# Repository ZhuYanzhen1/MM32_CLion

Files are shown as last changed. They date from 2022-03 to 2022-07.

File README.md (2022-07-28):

# MM32_CLion

&nbsp;&nbsp;&nbsp;&nbsp;&nbsp;&nbsp;&nbsp;&nbsp;&nbsp;&nbsp;&nbsp;&nbsp;English / [中文](https://github.com/ZhuYanzhen1/MM32_CLion/blob/master/README_CN.md)

&nbsp;&nbsp;&nbsp;&nbsp;This project is a Windows CLion IDE file for the MM32F3277G9 chip and a circuit design for the main control board based on the MM32F3277G9 chip. The software code contains the link files required for GCC, CMake files, clang-format files, Doxygen configuration files, etc. to ensure that this package is ready to use when it arrives. The hardware mainly contains the schematic and PCB files, and the Gerber files will be released in the form of Releases.The adapted tuning tool is developed using Qt, and the repository contains the Qt source code files for the tool. Some Python scripting tools are also provided for easy development, such as scripts for calculating filter parameters.<br>
&nbsp;&nbsp;&nbsp;&nbsp;This project is developed around the 2022 National Student Intelligent Vehicle Competition. Complex algorithms such as LQR controller, multi-rate Kalman fusion, and advanced development tools such as unit testing and continuous integration are innovatively used in this project for development, which greatly improves the development efficiency and reduces the development cost.

***

### Develop Environment

+ Integrated Development Environment: CLion CL-221.5921.27
+ OS: Windows 10 Professional 21H2 x64 10.0.19044
+ Make tool: GNU Make 4.3 x86_64-w64-mingw32
+ Compiler tool chain: gcc-arm-none-eabi 10.3.1 20210824
+ Burning tool: OpenOCD 0.11.0+dev-00449-gb2ab2241f+ (2021-11-13-20:25)
+ Documentation tool: Doxygen GUI 1.9.4 (Qt version 5.15.2)
+ EDA tool: KiCAD 6.0.5 (VC++ 1929, 64bit)
+ Qt environment: Qt 5.14.2 (MSVC 2017, 32bit)
+ Python version: Python 3.10.5 [MSC v.1929 64 bit (AMD64)] on win32

***

### Directory Structure

+ .github: Configuration file for the continuous integration of Github Actions.
+ circuit: Schematics and PCB files related to the project.
  + bldc_driver: Schematic and PCB file of the brushless driver board.
  + control_board: Schematic and PCB file of the main control board.
  + geomagnetometer: Schematic and PCB file of geomagnetometer board.
  + power_board: Schematic and PCB file of the power supply board.
  + uart_tt_mcu: Schematic and PCB file of serial transmission module microcontroller side.
  + uart_tt_pc: Schematic and PCB file of the PC side of the serial port pass-through module.
  + wireless_debugger: Schematic and PCB file of the wireless debugger.
+ docs: html documents and related images and board interactive BOMs generated by Doxygen.
+ mechanical: 3D model files of non-standard mechanical parts.
  + battery_mount: 3D model file of the battery mount.
  + car_shell: 3D model file of the car shell.
  + control_board_mount: 3D model file of main control board and power board bracket.
  + magnometer_mount: 3D model file of geomagnetometer bracket.
+ program: Source file and configuration file of the main controller program.
  + ctrl_mcu: control MCU user layer code, main logic implementation.
  + debug: transmission layer code and CMBackTrace program file for implementing serial port tuning reference.
  + device: Device specific data link layer protocol to implement device level register read/write.
  + fatfs: code related to the FAT file system.
  + form: All form controls and form actions for the display.
  + freertos: code for the FreeRTOS real-time operating system.
  + gui: the relevant drawing functions and forms code implementation for the display.
  + hardware: initialization and read/write code related to MM32F3277G9P chip peripherals.
  + library: code for the HAL library of the MM32F3277G9P chip provided by MindMotion.
  + math: code and functions related to math calculation, such as checksum calculation, FFT, etc.
  + proc_mcu: Handling MCU user layer code, main logic implementation.
  + protocol: data link layer transmission protocol for [sdtp and mdtp](https://github.com/ZhuYanzhen1/CDTP).
  + system: initialization and operation code related to MM32F3277G9P system.
+ scripts: Python script files used to facilitate program testing and design.
+ testbench: CUnit library-based unit test code for testing functions.
+ tools: Qt tuning tool source code used for tuning parameters.

***

### License

**Affiliation：AcmeTech<br>
Author: Yanzhen Zhu, Guilin Zhao, Hanbing Lai<br>
Maintainer：Yanzhen Zhu, Guilin Zhao, 2208213223@qq.com, 1662568794@qq.com**

&nbsp;&nbsp;&nbsp;&nbsp;The source code is released under a [AGPL-3.0 License](https://github.com/ZhuYanzhen1/MM32_CLion/blob/master/LICENSE).The product has been tested under Windows 10 and Ubuntu 18.04 and 20.04. This is research code, expect that it changes often and any fitness for a particular purpose is disclaimed.

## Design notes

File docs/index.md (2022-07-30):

## Welcome to GitHub Pages / 欢迎来到GitHub Pages
&nbsp;&nbsp;&nbsp;&nbsp;This Github Pages page is used to deploy and display report files automatically generated or manually exported through Github Actions, interactive BOMs for boards, and description manuals for program code. This page is a guide page, and you can go to it by clicking the appropriate option.<br>
&nbsp;&nbsp;&nbsp;&nbsp;本Github Pages页面用于部署和展示通过Github Actions自动生成或手动导出的报告文件、电路板的交互式BOM以及程序代码的描述手册。本页面是引导页，你可以通过点击相应选项前往该页面。

***

### Program Manual / 程序手册
[Program Manual / 程序手册](https://zhuyanzhen1.github.io/MM32_CLion/doxygen/index.html)

***

### Unit Test / 单元测试
[Unit Test Results / 单元测试结果](https://zhuyanzhen1.github.io/MM32_CLion/unit_test/Report-Results.xml)<br>
[Unit Test List / 单元测试列表](https://zhuyanzhen1.github.io/MM32_CLion/unit_test/Report-Listing.xml)

***

### Interactive BOM / 交互式BOM
[Interactive BOM for ControlBoard / 主控板交互式BOM](https://zhuyanzhen1.github.io/MM32_CLion/circuit/control_board_ibom.html)<br>
[Interactive BOM for BLDC Driver / 无刷电机驱动板交互式BOM](https://zhuyanzhen1.github.io/MM32_CLion/circuit/bldc_driver_ibom.html)<br>
[Interactive BOM for Wireless Debugger / 无线调试器交互式BOM](https://zhuyanzhen1.github.io/MM32_CLion/circuit/wireless_debugger_ibom.html)<br>
[Interactive BOM for PC-side Wireless Serial / PC端串口透传交互式BOM](https://zhuyanzhen1.github.io/MM32_CLion/circuit/uart_tt_pc_ibom.html)<br>
[Interactive BOM for MCU-side Wireless Serial / MCU端串口透传交互式BOM](https://zhuyanzhen1.github.io/MM32_CLion/circuit/uart_tt_mcu_ibom.html)<br>
[Interactive BOM for Geomagnometer / 地磁计交互式BOM](https://zhuyanzhen1.github.io/MM32_CLion/circuit/geomagnetometer_ibom.html)

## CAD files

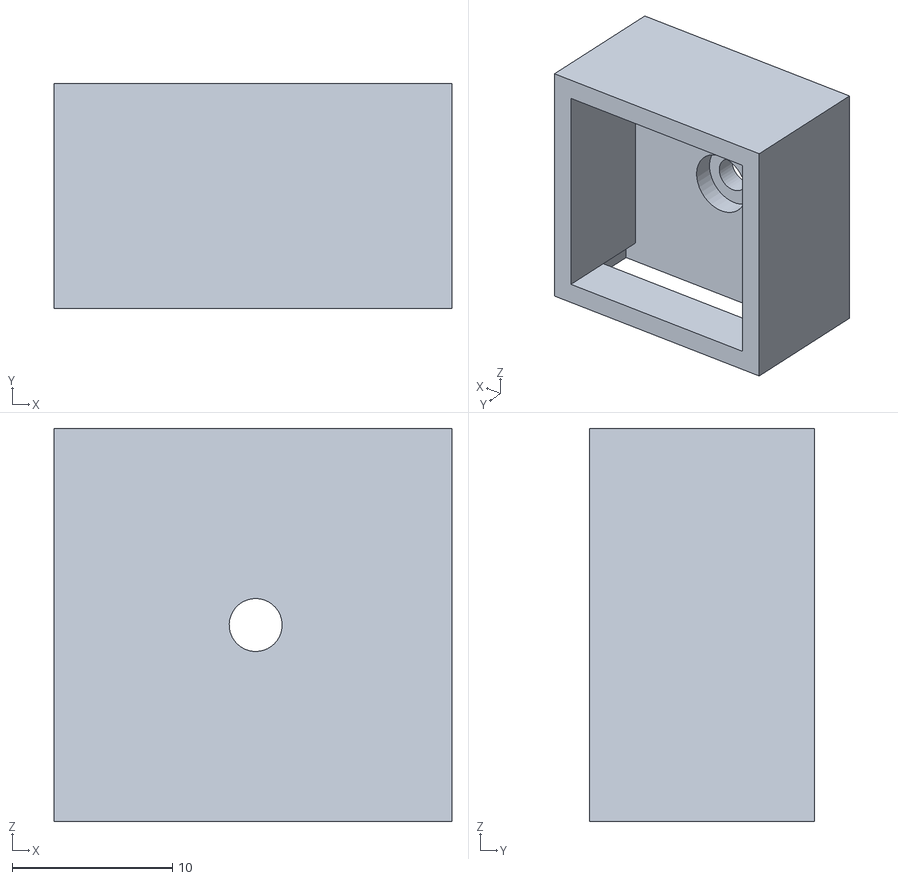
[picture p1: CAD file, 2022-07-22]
mechanical/magnometer_mount.STL
24.8 x 14.0 x 24.5

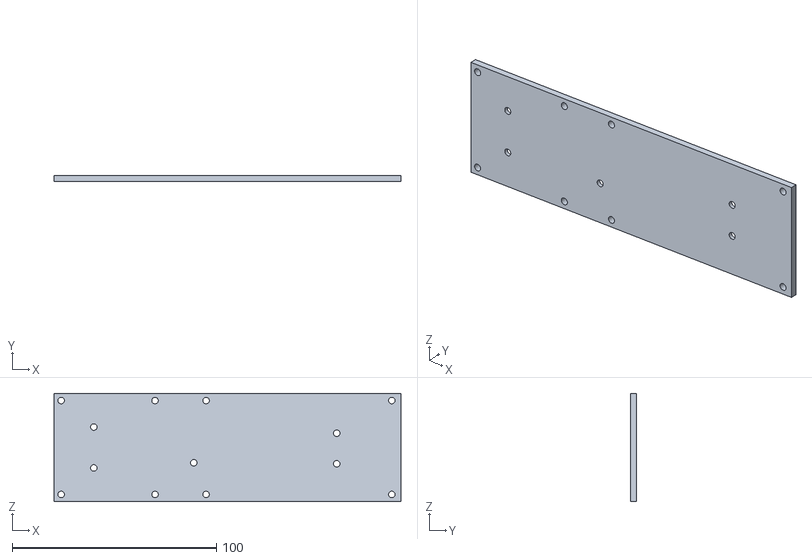
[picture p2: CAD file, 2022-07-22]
mechanical/controlboard_mount.STL
170.0 x 3.00 x 53.0

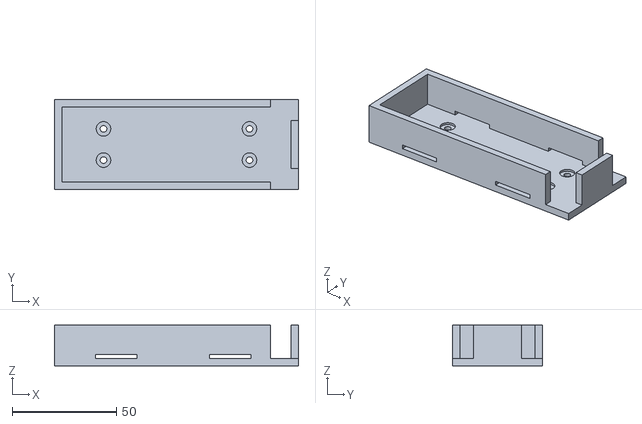
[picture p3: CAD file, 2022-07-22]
mechanical/baterry_mount.STL
117.0 x 43.0 x 19.5

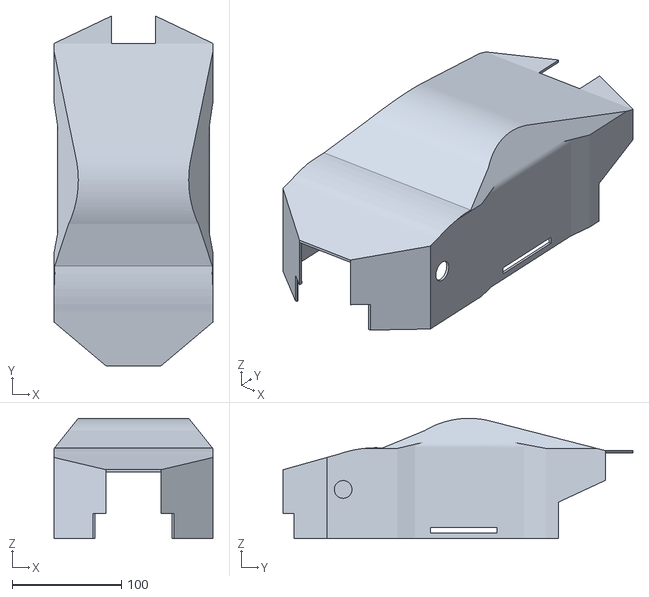
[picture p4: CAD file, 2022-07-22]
mechanical/car_shell.stl
145.0 x 320.0 x 110.0

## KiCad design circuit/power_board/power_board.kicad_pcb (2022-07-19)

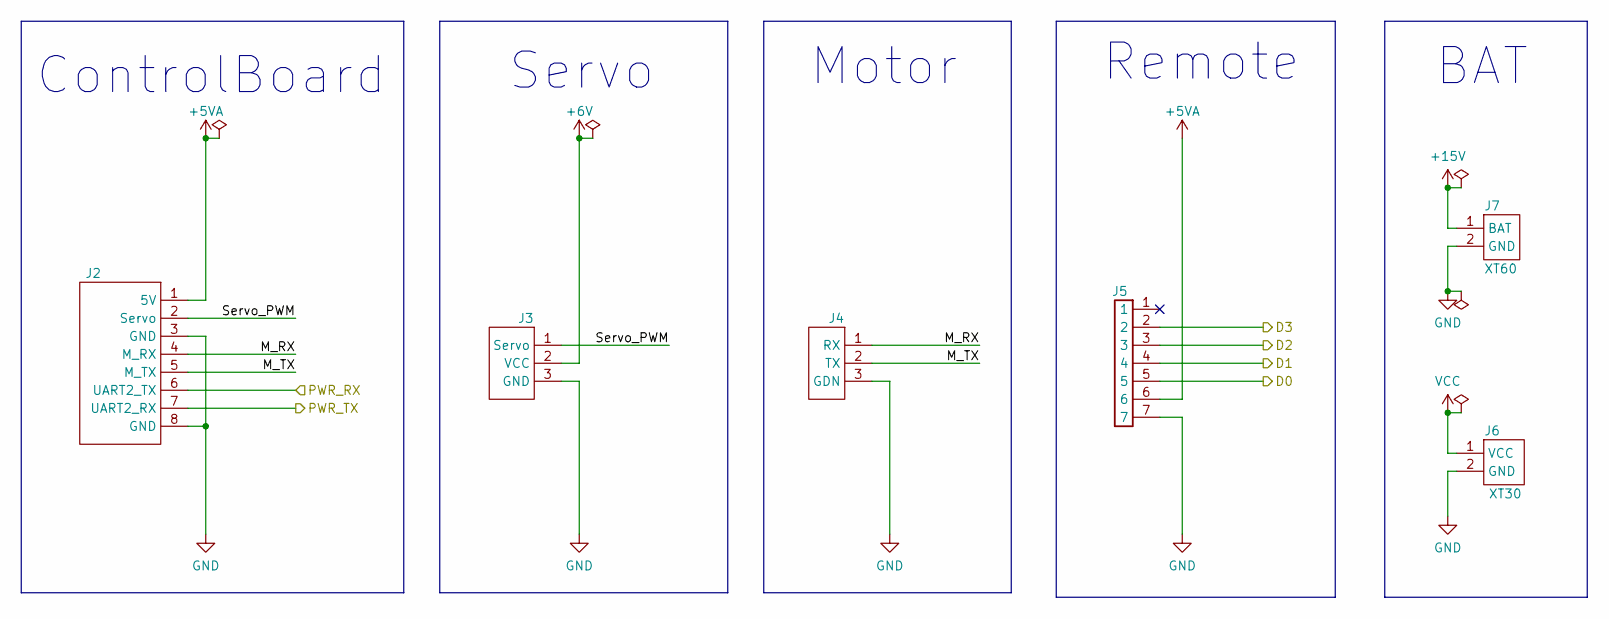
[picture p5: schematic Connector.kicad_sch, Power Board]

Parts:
J2: GH1.25_1x8; JST_GH_SM08B-GHS-TB_1x08-1MP_P1.25mm_Horizontal
J3: conn_1x3; PinSocket_1x03_P2.54mm_Vertical
J4: GH1.25_1X3; JST_GH_SM03B-GHS-TB_1x03-1MP_P1.25mm_Horizontal
J5: CONN_1X7; PinHeader_1x07_P2.54mm_Vertical
J6: XT30; AMASS_XT30UPB-F_1x02_P5.0mm_Vertical
J7: XT60; AMASS_XT60-M_1x02_P7.20mm_Vertical

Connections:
+5VA: J2.1 (5V), J5.6; also elsewhere on the board
+6V: J3.2 (VCC); also elsewhere on the board
+15V: J7.1 (BAT); also elsewhere on the board
/Connector/D0: J5.5; also elsewhere on the board
/Connector/D1: J5.4; also elsewhere on the board
/Connector/D2: J5.3; also elsewhere on the board
/Connector/D3: J5.2; also elsewhere on the board
/Connector/M_RX: J2.4 (M_RX), J4.1 (RX)
/Connector/M_TX: J2.5 (M_TX), J4.2 (TX)
/Connector/PWR_RX: J2.6 (UART2_TX); also elsewhere on the board
/Connector/PWR_TX: J2.7 (UART2_RX); also elsewhere on the board
/Connector/Servo_PWM: J2.2 (Servo), J3.1 (Servo)
GND: J2.3 (GND), J2.8 (GND), J3.3 (GND), J4.3 (GDN), J5.7, J6.2 (GND), J7.2 (GND); also elsewhere on the board
VCC: J6.1 (VCC); also elsewhere on the board

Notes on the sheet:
Remote
BAT
Servo
Motor
ControlBoard

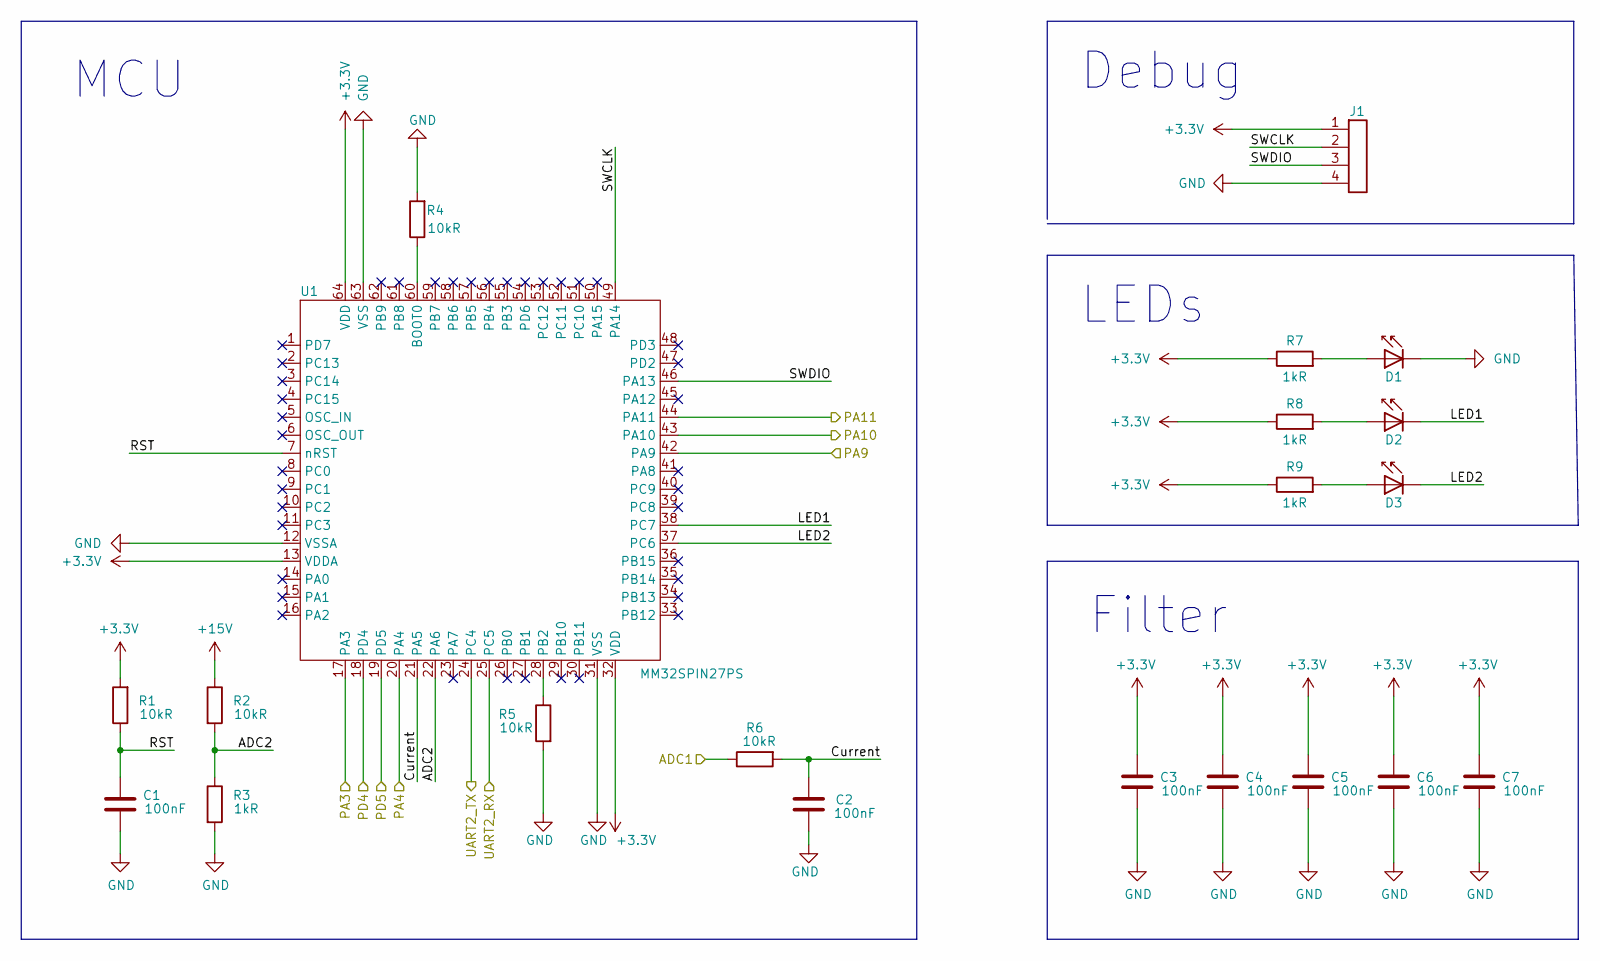
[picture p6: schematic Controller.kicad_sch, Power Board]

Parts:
C1, C2, C3, C4, C5, C6, C7: 100nF; C_0603_1608Metric_Pad1.08x0.95mm_HandSolder
D1, D2, D3: LED; LED_0603_1608Metric
J1: Conn_01x04; PinHeader_1x04_P2.54mm_Vertical
R1, R2, R4, R5, R6: 10kR; R_0603_1608Metric_Pad0.98x0.95mm_HandSolder
R3, R7, R8, R9: 1kR; R_0603_1608Metric_Pad0.98x0.95mm_HandSolder
U1: MM32SPIN27PS; LQFP-64_10x10mm_P0.5mm

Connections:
+3V3: C3.2, C4.2, C5.2, C6.2, C7.2, J1.1, R1.2, R7.1, R8.1, R9.1, U1.13 (VDDA), U1.32 (VDD), U1.64 (VDD); also elsewhere on the board
+15V: R2.1; also elsewhere on the board
/Connector/D0: U1.20 (PA4); also elsewhere on the board
/Connector/D1: U1.19 (PD5); also elsewhere on the board
/Connector/D2: U1.18 (PD4); also elsewhere on the board
/Connector/D3: U1.17 (PA3); also elsewhere on the board
/Connector/PWR_RX: U1.24 (PC4); also elsewhere on the board
/Connector/PWR_TX: U1.25 (PC5); also elsewhere on the board
/Controller/ADC1: R6.1; also elsewhere on the board
/Controller/ADC2: R2.2, R3.1, U1.22 (PA6)
/Controller/Current: C2.1, R6.2, U1.21 (PA5)
/Controller/LED1: D2.1 (K), U1.38 (PC7)
/Controller/LED2: D3.1 (K), U1.37 (PC6)
/Controller/PA9: U1.42 (PA9); also elsewhere on the board
/Controller/PA10: U1.43 (PA10); also elsewhere on the board
/Controller/PA11: U1.44 (PA11); also elsewhere on the board
/Controller/RST: C1.1, R1.1, U1.7 (nRST)
/Controller/SWCLK: J1.2, U1.49 (PA14)
/Controller/SWDIO: J1.3, U1.46 (PA13)
GND: C1.2, C2.2, C3.1, C4.1, C5.1, C6.1, C7.1, D1.1 (K), J1.4, R3.2, R4.2, R5.2, U1.12 (VSSA), U1.31 (VSS), U1.63 (VSS); also elsewhere on the board
unnamed: D1.2 (A), R7.2
unnamed: D2.2 (A), R8.2
unnamed: D3.2 (A), R9.2
unnamed: R4.1, U1.60 (BOOT0)
unnamed: R5.1, U1.28 (PB2)

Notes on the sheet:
MCU
Filter
Debug
LEDs

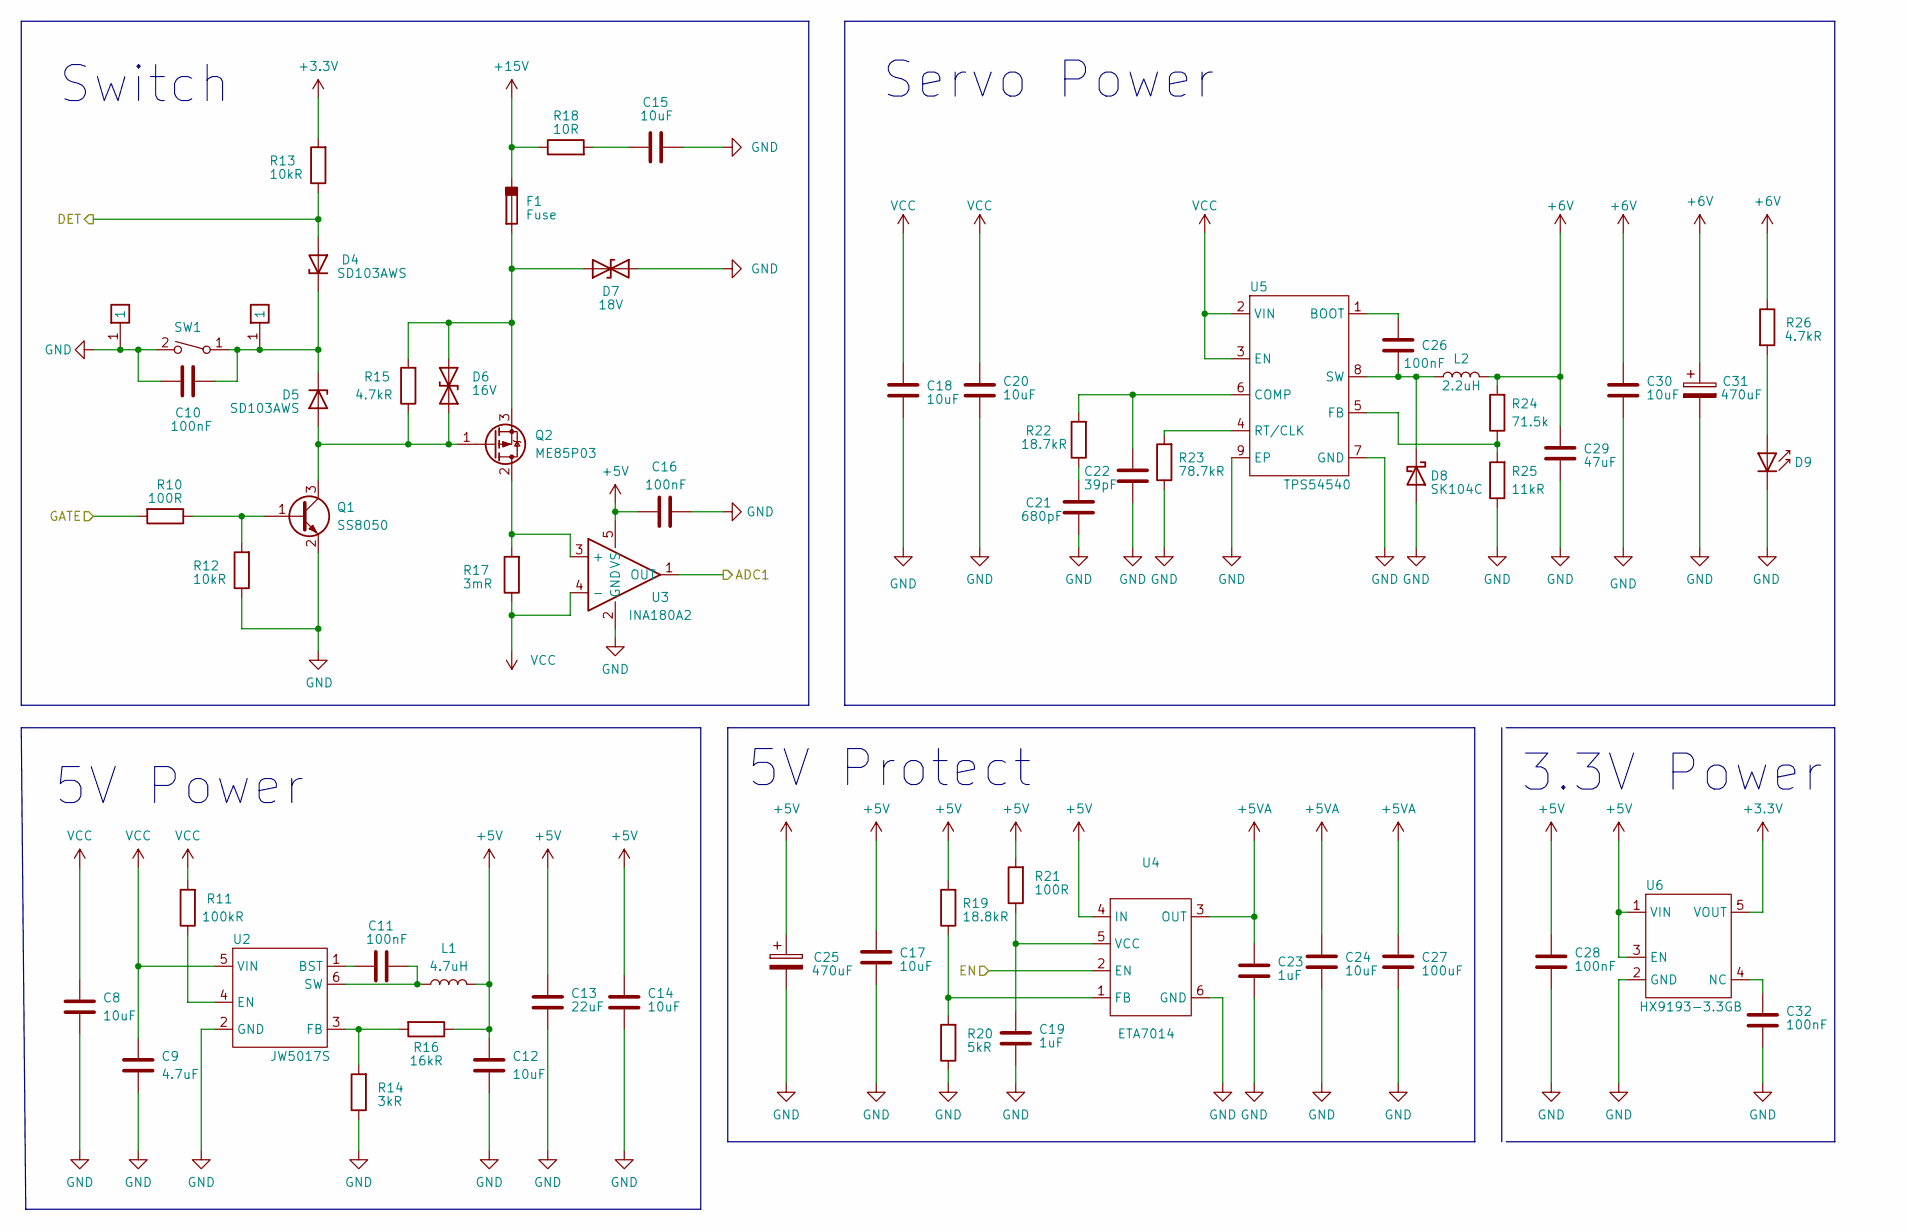
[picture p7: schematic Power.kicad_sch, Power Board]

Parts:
C8, C15, C18, C20, C30: 10uF; C_1206_3216Metric_Pad1.33x1.80mm_HandSolder
C9: 4.7uF; C_1206_3216Metric_Pad1.33x1.80mm_HandSolder
C10, C11, C16, C26, C28, C32: 100nF; C_0603_1608Metric_Pad1.08x0.95mm_HandSolder
C12, C14, C17, C24: 10uF; C_0603_1608Metric_Pad1.08x0.95mm_HandSolder
C13: 22uF; C_0603_1608Metric_Pad1.08x0.95mm_HandSolder
C19, C23: 1uF; C_0603_1608Metric_Pad1.08x0.95mm_HandSolder
C21: 680pF; C_0603_1608Metric_Pad1.08x0.95mm_HandSolder
C22: 39pF; C_0603_1608Metric_Pad1.08x0.95mm_HandSolder
C25, C31: 470uF; CP_Radial_D6.3mm_P2.50mm
C27: 100uF; C_1210_3225Metric_Pad1.33x2.70mm_HandSolder
C29: 47uF; C_1206_3216Metric_Pad1.33x1.80mm_HandSolder
D4, D5: SD103AWS; D_SOD-323_HandSoldering
D6: 16V; D_SMB
D7: 18V; D_SMB
D8: SK104C; D_SMC
D9: LED; LED_0603_1608Metric
F1: Fuse; Fuse_1206_3216Metric
J8, J9: conn_1x1; PinSocket_1x01_P2.54mm_Vertical
L1: 4.7uH; IND-SMD_L4.6-W4.2_SMMS0420
L2: 2.2uH; L_10.4x10.4_H4.8
Q1: SS8050; SOT-23
Q2: ME85P03; TO-252-2
R10, R21: 100R; R_0603_1608Metric_Pad0.98x0.95mm_HandSolder
R11: 100kR; R_0603_1608Metric_Pad0.98x0.95mm_HandSolder
R12, R13: 10kR; R_0603_1608Metric_Pad0.98x0.95mm_HandSolder
R14: 3kR; R_0603_1608Metric_Pad0.98x0.95mm_HandSolder
R15: 4.7kR; R_0805_2012Metric_Pad1.20x1.40mm_HandSolder
R16: 16kR; R_0603_1608Metric_Pad0.98x0.95mm_HandSolder
R17: 3mR; R_2512_6332Metric
R18: 10R; R_1206_3216Metric
R19: 18.8kR; R_0603_1608Metric_Pad0.98x0.95mm_HandSolder
R20: 5kR; R_0603_1608Metric_Pad0.98x0.95mm_HandSolder
R22: 18.7kR; R_0603_1608Metric_Pad0.98x0.95mm_HandSolder
R23: 78.7kR; R_0603_1608Metric_Pad0.98x0.95mm_HandSolder
R24: 71.5k; R_0603_1608Metric_Pad0.98x0.95mm_HandSolder
R25: 11kR; R_0603_1608Metric_Pad0.98x0.95mm_HandSolder
R26: 4.7kR; R_0603_1608Metric_Pad0.98x0.95mm_HandSolder
SW1: KEY; SW_SPST_CK_RS282G05A3
U2: JW5017S; SOT-23-6
U3: INA180A2; SOT-23-5
U4: ETA7014; TSOT-23-6
U5: TPS54540; SOIC-8-1EP_3.9x4.9mm_P1.27mm_EP2.29x3mm
U6: HX9193-3.3GB; SOT-23-5

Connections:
+3V3: R13.2, U6.5 (VOUT); also elsewhere on the board
+5V: C12.2, C13.2, C14.2, C16.2, C17.2, C25.1, C28.2, L1.2, R16.1, R19.2, R21.2, U3.5 (VS), U4.4 (IN), U6.1 (VIN), U6.3 (EN)
+5VA: C23.2, C24.2, C27.2, U4.3 (OUT); also elsewhere on the board
+6V: C29.2, C30.2, C31.1, L2.2, R24.2, R26.1; also elsewhere on the board
+15V: F1.1, R18.1; also elsewhere on the board
/Controller/ADC1: U3.1 (OUT); also elsewhere on the board
/Controller/PA9: D4.2 (A), R13.1; also elsewhere on the board
/Controller/PA10: R10.2; also elsewhere on the board
/Controller/PA11: U4.2 (EN); also elsewhere on the board
GND: C8.1, C9.1, C10.1, C12.1, C13.1, C14.1, C15.1, C16.1, C17.1, C18.1, C19.1, C20.1, C21.1, C22.1, C23.1, C24.1, C25.2, C27.1, C28.1, C29.1, C30.1, C31.2, C32.1, D7.1 (A1), D8.2 (A), D9.1 (K), J8.1, Q1.2 (E), R12.1, R14.1, R20.1, R23.1, R25.1, SW1.2, U2.2 (GND), U3.2 (GND), U4.6 (GND), U5.7 (GND), U5.9 (EP), U6.2 (GND); also elsewhere on the board
unnamed: C10.2, D4.1 (K), D5.1 (K), J9.1, SW1.1
unnamed: C11.1, L1.1, U2.6 (SW)
unnamed: C11.2, U2.1 (BST)
unnamed: C15.2, R18.2
unnamed: C19.2, R21.1, U4.5 (VCC)
unnamed: C21.2, R22.1
unnamed: C22.2, R22.2, U5.6 (COMP)
unnamed: C26.1, D8.1 (K), L2.1, U5.8 (SW)
unnamed: C26.2, U5.1 (BOOT)
unnamed: C32.2, U6.4 (NC)
unnamed: D5.2 (A), D6.1 (A1), Q1.3 (C), Q2.1 (G), R15.1
unnamed: D6.2 (A2), D7.2 (A2), F1.2, Q2.3 (S), R15.2
unnamed: D9.2 (A), R26.2
unnamed: Q1.1 (B), R10.1, R12.2
unnamed: Q2.2 (D), R17.2, U3.3 (+)
unnamed: R11.1, U2.4 (EN)
unnamed: R14.2, R16.2, U2.3 (FB)
unnamed: R19.1, R20.2, U4.1 (FB)
unnamed: R23.2, U5.4 (RT/CLK)
unnamed: R24.1, R25.2, U5.5 (FB)
VCC: C8.2, C9.2, C18.2, C20.2, R11.2, R17.1, U2.5 (VIN), U3.4 (-), U5.2 (VIN), U5.3 (EN); also elsewhere on the board

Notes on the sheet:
5V Protect
Servo Power
5V Power
Switch
3.3V Power

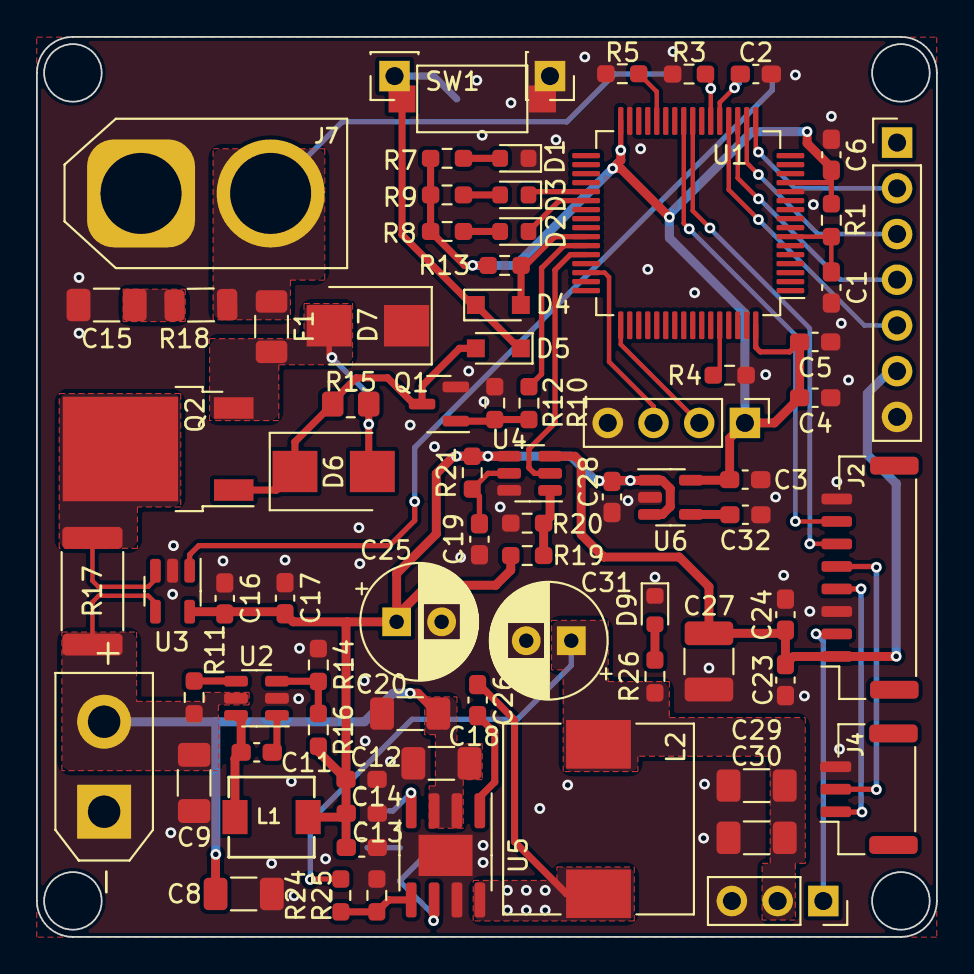
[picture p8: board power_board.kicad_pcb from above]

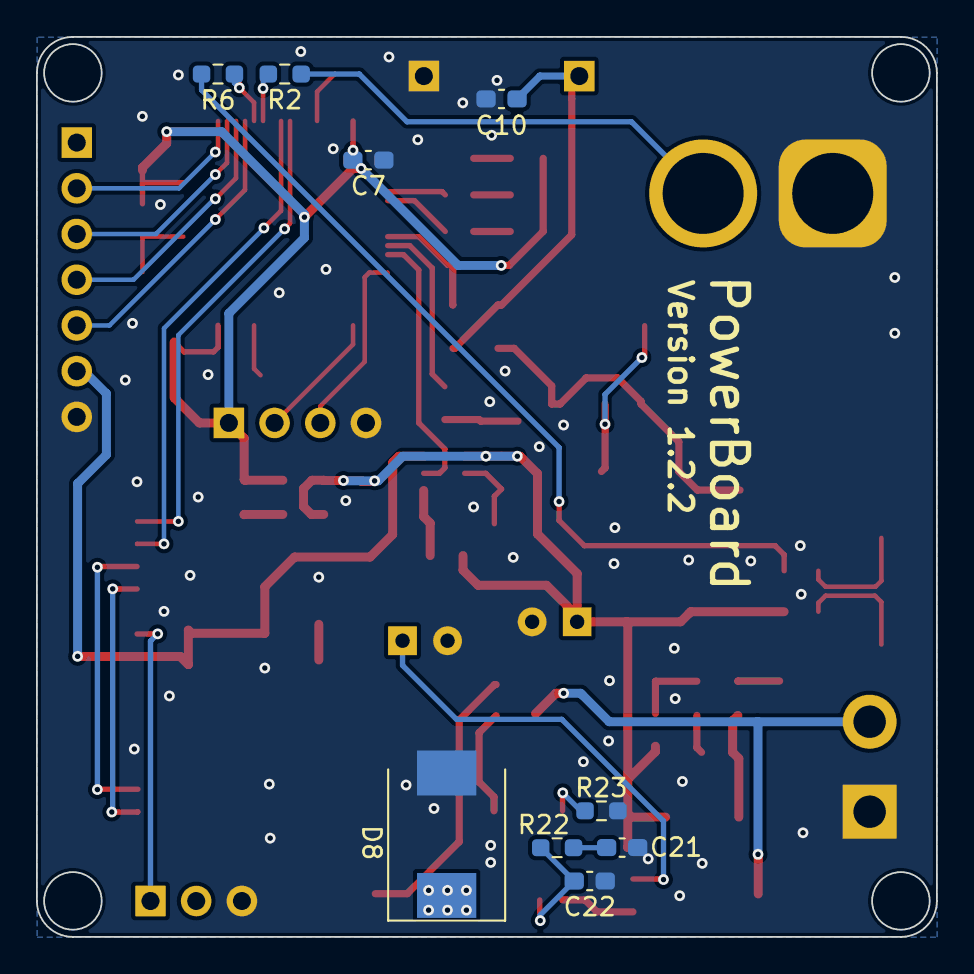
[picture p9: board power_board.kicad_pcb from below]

Board: 2 copper layers, 50.0 x 50.0 mm, 88 parts (9 on the bottom side), 52 nets.

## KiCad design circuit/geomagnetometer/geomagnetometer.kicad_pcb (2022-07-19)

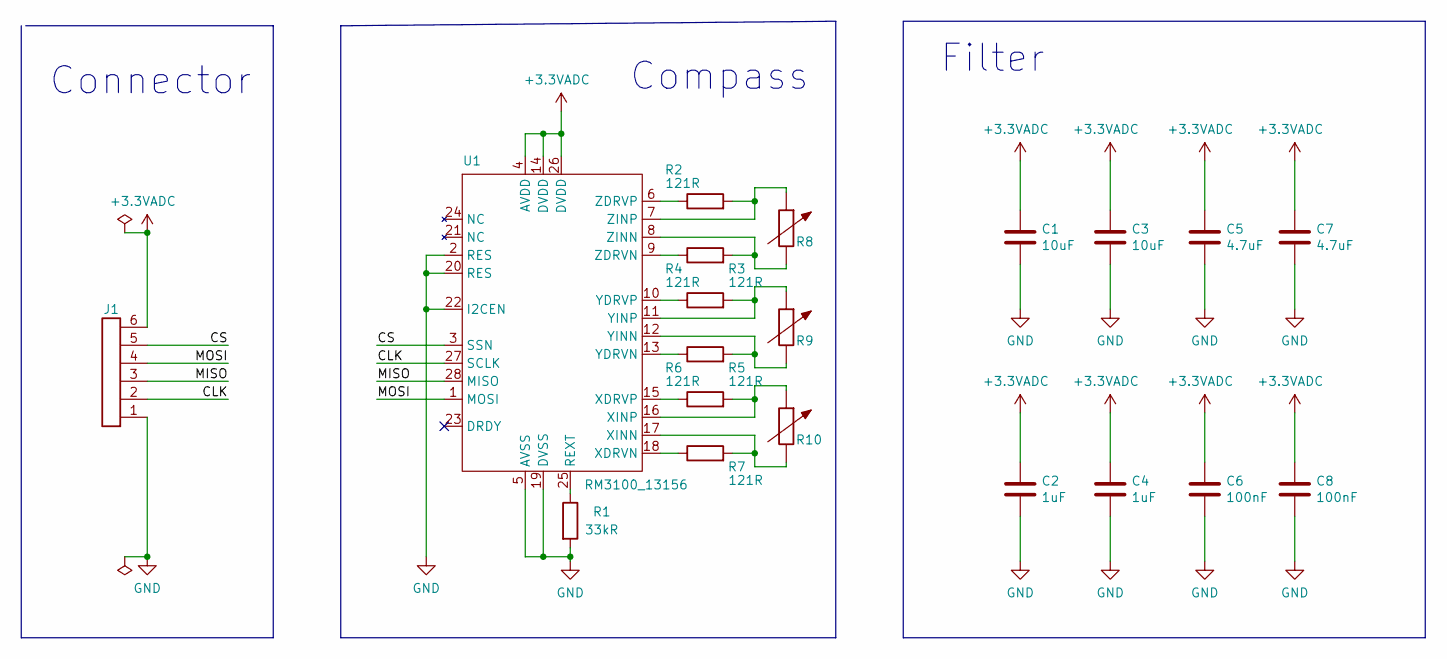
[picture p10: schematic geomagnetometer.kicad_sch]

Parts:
C1, C3: 10uF; C_0603_1608Metric
C2, C4: 1uF; C_0603_1608Metric
C5, C7: 4.7uF; C_0603_1608Metric
C6, C8: 100nF; C_0603_1608Metric
J1: Conn_01x06; JST_GH_SM06B-GHS-TB_1x06-1MP_P1.25mm_Horizontal
R1: 33kR; R_0603_1608Metric
R2, R3, R4, R5, R6, R7: 121R; R_0603_1608Metric
R8: PN13101(Z); PN13101
R9, R10: PN13104(XY); PN13104
U1: RM3100_13156; QFN-28-1EP_4x4mm_P0.4mm_EP2.4x2.4mm

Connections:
+3.3VADC: C1.1, C2.1, C3.1, C4.1, C5.1, C6.1, C7.1, C8.1, J1.6, U1.4 (AVDD), U1.14 (DVDD), U1.26 (DVDD)
/CLK: J1.2, U1.27 (SCLK)
/CS: J1.5, U1.3 (SSN)
/MISO: J1.3, U1.28 (MISO)
/MOSI: J1.4, U1.1 (MOSI)
GND: C1.2, C2.2, C3.2, C4.2, C5.2, C6.2, C7.2, C8.2, J1.1, R1.2, U1.2 (RES), U1.5 (AVSS), U1.19 (DVSS), U1.20 (RES), U1.22 (I2CEN), U1.29
unnamed: R1.1, U1.25 (REXT)
unnamed: R2.1, U1.6 (ZDRVP)
unnamed: R2.2, R8.2 (B), U1.7 (ZINP)
unnamed: R3.1, U1.9 (ZDRVN)
unnamed: R3.2, R8.1 (A), U1.8 (ZINN)
unnamed: R4.1, U1.10 (YDRVP)
unnamed: R4.2, R9.2 (B), U1.11 (YINP)
unnamed: R5.1, U1.13 (YDRVN)
unnamed: R5.2, R9.1 (A), U1.12 (YINN)
unnamed: R6.1, U1.15 (XDRVP)
unnamed: R7.1, U1.18 (XDRVN)
unnamed: R7.2, R10.1 (A), U1.17 (XINN)
unnamed: R6.2, R10.2 (B), U1.16 (XINP)

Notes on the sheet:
Compass
Filter
Connector

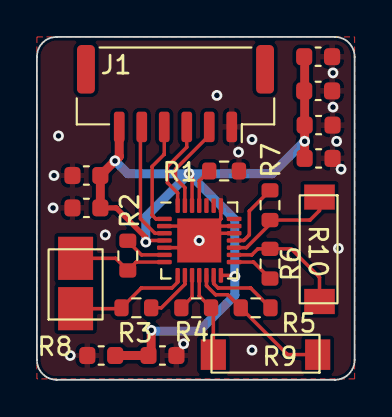
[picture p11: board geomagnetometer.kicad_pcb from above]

Board: 2 copper layers, 17.6 x 19.1 mm, 20 parts (0 on the bottom side), 19 nets.

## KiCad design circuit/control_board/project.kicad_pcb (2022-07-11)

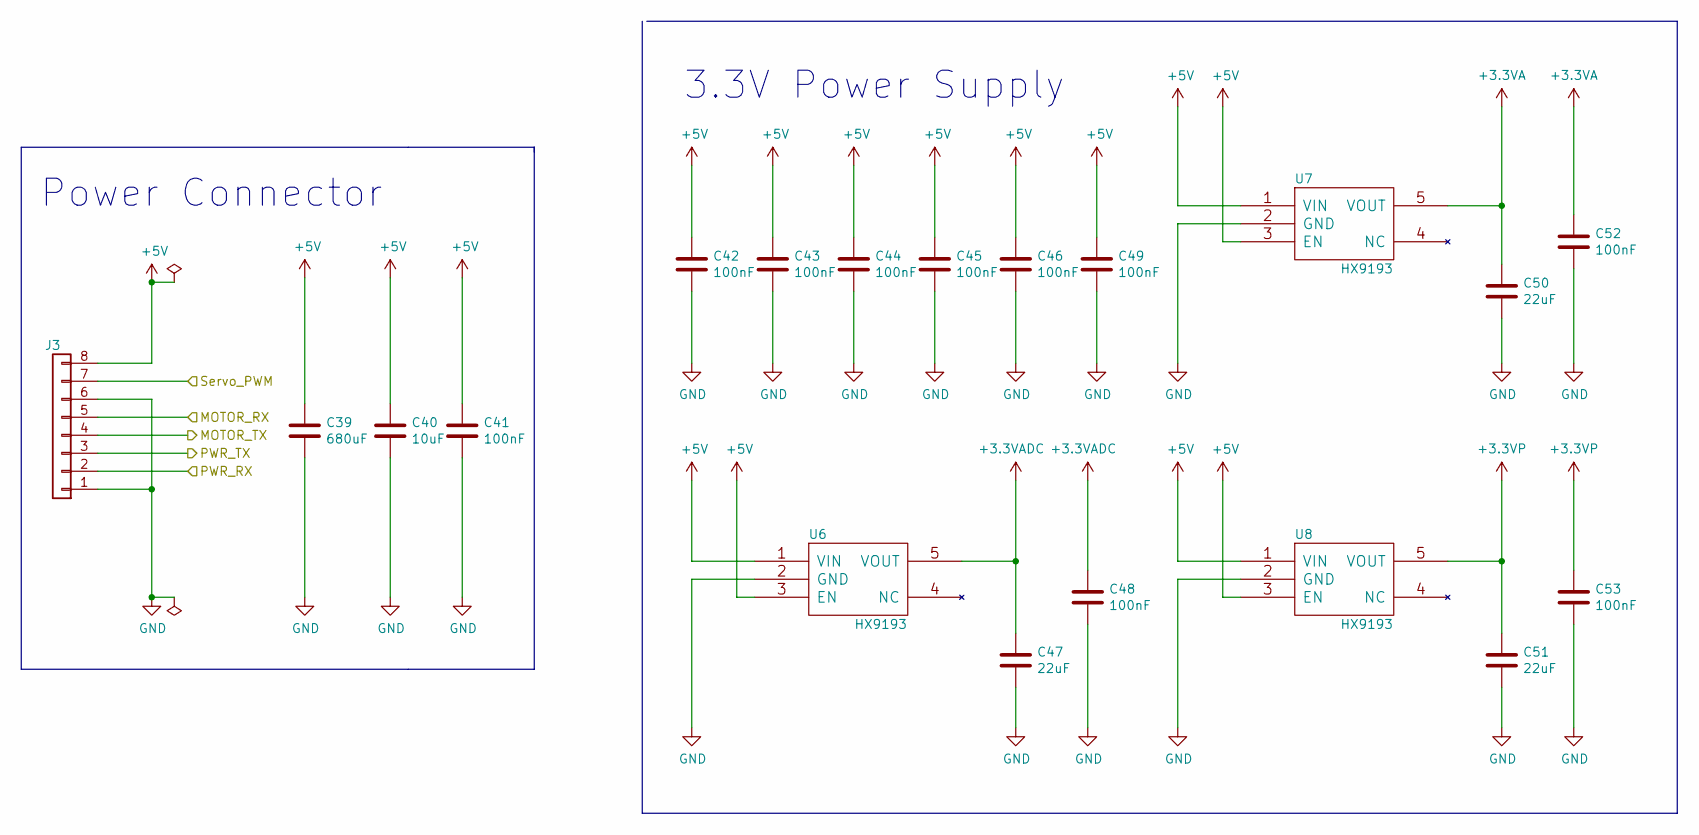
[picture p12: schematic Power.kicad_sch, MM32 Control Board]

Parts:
C39: 680uF; Cap_SinkBoard
C40: 10uF; C_0603_1608Metric
C41, C42, C43, C44, C45, C46, C48, C49, C52, C53: 100nF; C_0603_1608Metric
C47, C50, C51: 22uF; C_0603_1608Metric
J3: Conn_01x08; JST_PH_S8B-PH-K_1x08_P2.00mm_Horizontal
U6, U7, U8: HX9193; SOT-23-5

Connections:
+3.3VA: C50.1, C52.1, U7.5 (VOUT); also elsewhere on the board
+3.3VADC: C47.1, C48.1, U6.5 (VOUT); also elsewhere on the board
+3.3VP: C51.1, C53.1, U8.5 (VOUT); also elsewhere on the board
+5V: C39.1, C40.1, C41.1, C42.1, C43.1, C44.1, C45.1, C46.1, C49.1, J3.8, U6.1 (VIN), U6.3 (EN), U7.1 (VIN), U7.3 (EN), U8.1 (VIN), U8.3 (EN); also elsewhere on the board
/Control_MCU/TIM3_CH1: J3.7; also elsewhere on the board
/Control_MCU/UART7_RX: J3.4; also elsewhere on the board
/Control_MCU/UART7_TX: J3.5; also elsewhere on the board
/Power/PWR_RX: J3.2; also elsewhere on the board
/Power/PWR_TX: J3.3; also elsewhere on the board
GND: C39.2, C40.2, C41.2, C42.2, C43.2, C44.2, C45.2, C46.2, C47.2, C48.2, C49.2, C50.2, C51.2, C52.2, C53.2, J3.1, J3.6, U6.2 (GND), U7.2 (GND), U8.2 (GND); also elsewhere on the board

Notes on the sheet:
Power Connector
3.3V Power Supply

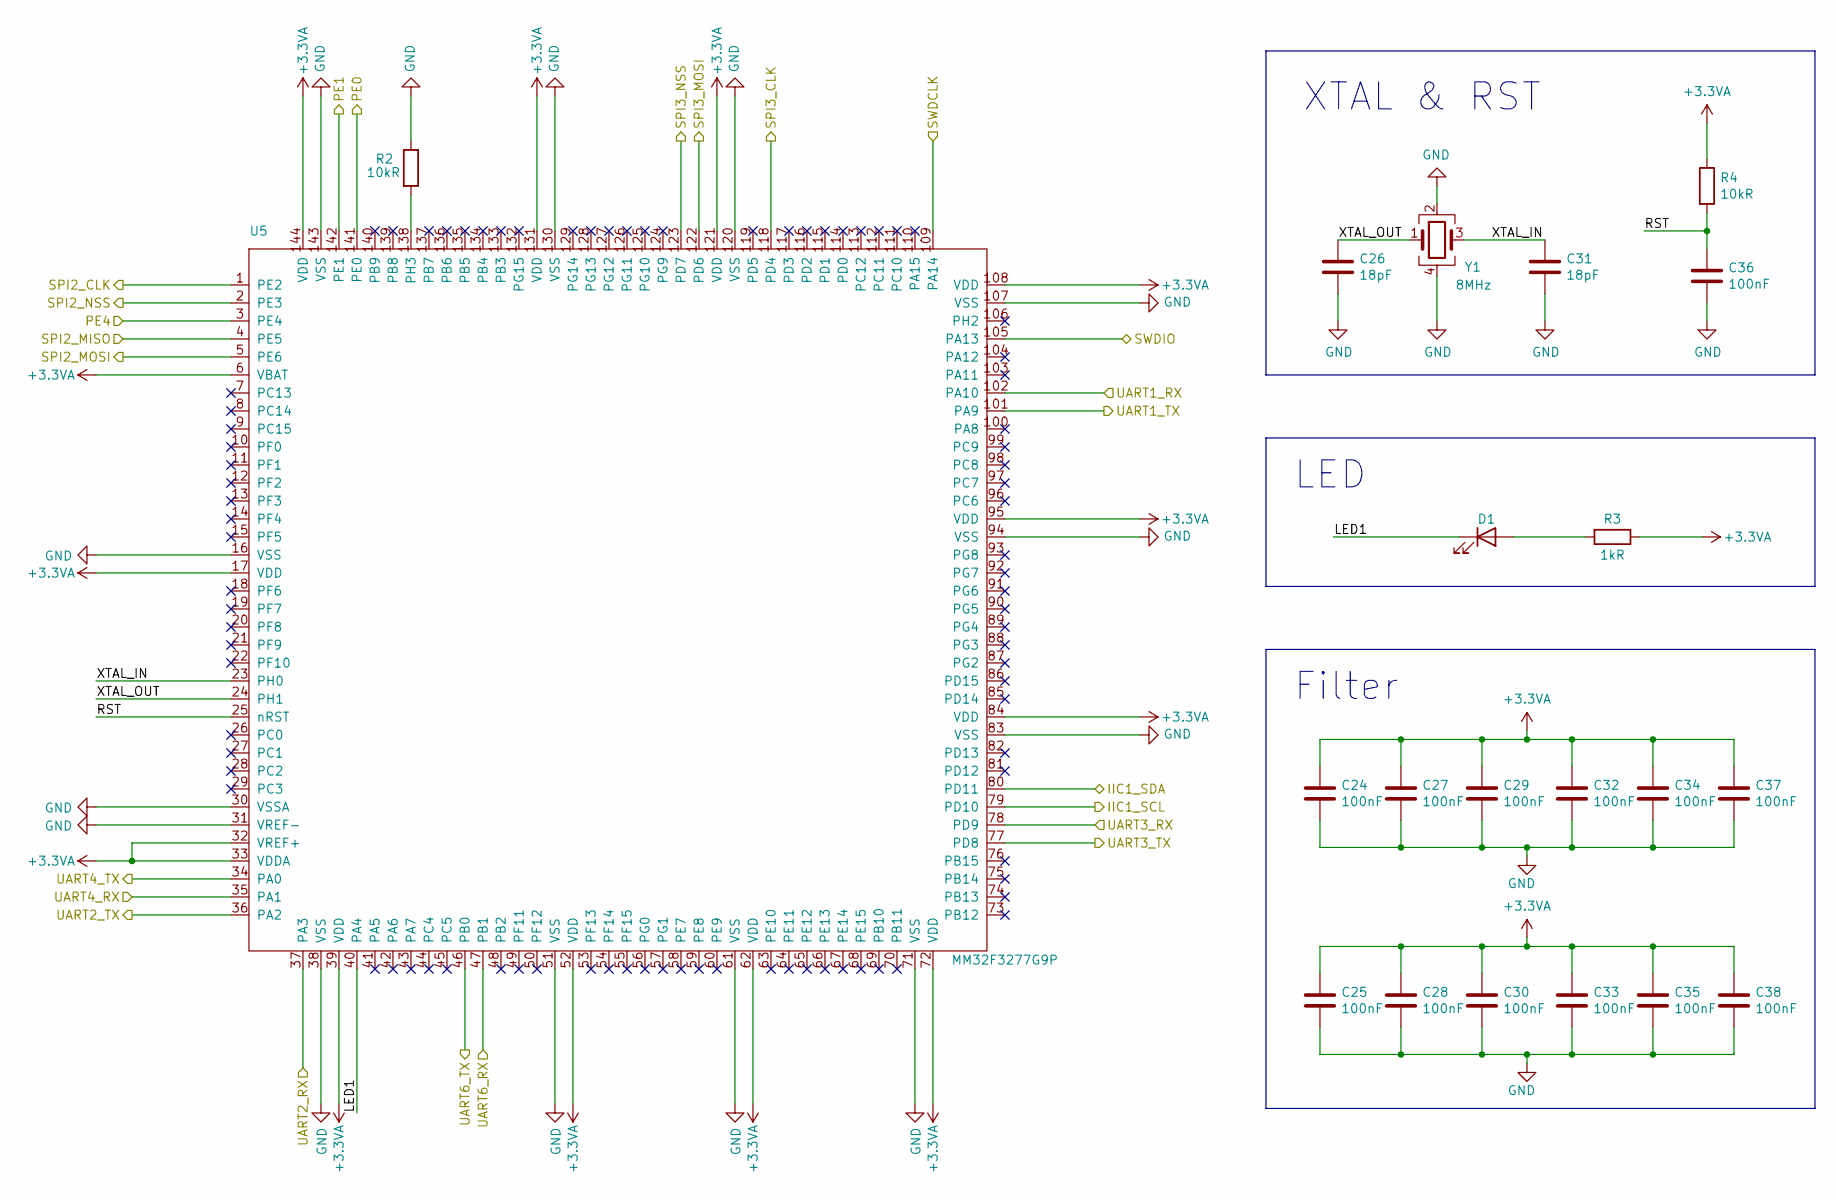
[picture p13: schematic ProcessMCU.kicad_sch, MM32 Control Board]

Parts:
C24, C25, C27, C28, C29, C30, C32, C33, C34, C35, C36, C37, C38: 100nF; C_0603_1608Metric
C26, C31: 18pF; C_0603_1608Metric
D1: LED; LED_0603_1608Metric
R2, R4: 10kR; R_0603_1608Metric
R3: 1kR; R_0603_1608Metric
U5: MM32F3277G9P; LQFP-144_20x20mm_P0.5mm
Y1: 8MHz; Crystal_SMD_3225-4Pin_3.2x2.5mm

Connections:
+3.3VA: C24.1, C25.1, C27.1, C28.1, C29.1, C30.1, C32.1, C33.1, C34.1, C35.1, C37.1, C38.1, R3.1, R4.1, U5.6 (VBAT), U5.17 (VDD), U5.32 (VREF+), U5.33 (VDDA), U5.39 (VDD), U5.52 (VDD), U5.62 (VDD), U5.72 (VDD), U5.84 (VDD), U5.95 (VDD), U5.108 (VDD), U5.121 (VDD), U5.131 (VDD), U5.144 (VDD); also elsewhere on the board
/Compass&Storage/EEPROM_SCL: U5.79 (PD10); also elsewhere on the board
/Compass&Storage/EEPROM_SDA: U5.80 (PD11); also elsewhere on the board
/Control_MCU/UART6_RX: U5.34 (PA0); also elsewhere on the board
/Control_MCU/UART6_TX: U5.35 (PA1); also elsewhere on the board
/Coprocessor/UART1_RX: U5.36 (PA2); also elsewhere on the board
/Coprocessor/UART1_TX: U5.37 (PA3); also elsewhere on the board
/Debugger/DBG_RX1: U5.101 (PA9); also elsewhere on the board
/Debugger/DBG_TX1: U5.102 (PA10); also elsewhere on the board
/Debugger/SWDCLK1: U5.109 (PA14); also elsewhere on the board
/Debugger/SWDIO1: U5.105 (PA13); also elsewhere on the board
/LCD&GPS/GPS_RX: U5.77 (PD8); also elsewhere on the board
/LCD&GPS/GPS_TX: U5.78 (PD9); also elsewhere on the board
/LCD&GPS/LCD_A0: U5.142 (PE1); also elsewhere on the board
/LCD&GPS/LCD_CLK: U5.118 (PD4); also elsewhere on the board
/LCD&GPS/LCD_CS: U5.123 (PD7); also elsewhere on the board
/LCD&GPS/LCD_MOSI: U5.122 (PD6); also elsewhere on the board
/LCD&GPS/LCD_RST: U5.141 (PE0); also elsewhere on the board
/LCD&GPS/TOUCH_CLK: U5.1 (PE2); also elsewhere on the board
/LCD&GPS/TOUCH_CS: U5.2 (PE3); also elsewhere on the board
/LCD&GPS/TOUCH_IT: U5.3 (PE4); also elsewhere on the board
/LCD&GPS/TOUCH_MISO: U5.4 (PE5); also elsewhere on the board
/LCD&GPS/TOUCH_MOSI: U5.5 (PE6); also elsewhere on the board
/Power/PWR_RX: U5.46 (PB0); also elsewhere on the board
/Power/PWR_TX: U5.47 (PB1); also elsewhere on the board
/Process_MCU/LED1: D1.1 (K), U5.40 (PA4)
/Process_MCU/RST: C36.1, R4.2, U5.25 (nRST)
/Process_MCU/XTAL_IN: C31.1, U5.23 (PH0), Y1.3
/Process_MCU/XTAL_OUT: C26.1, U5.24 (PH1), Y1.1
GND: C24.2, C25.2, C26.2, C27.2, C28.2, C29.2, C30.2, C31.2, C32.2, C33.2, C34.2, C35.2, C36.2, C37.2, C38.2, R2.1, U5.16 (VSS), U5.30 (VSSA), U5.31 (VREF-), U5.38 (VSS), U5.51 (VSS), U5.61 (VSS), U5.71 (VSS), U5.83 (VSS), U5.94 (VSS), U5.107 (VSS), U5.120 (VSS), U5.130 (VSS), U5.143 (VSS), Y1.2, Y1.4; also elsewhere on the board
unnamed: D1.2 (A), R3.2
unnamed: R2.2, U5.138 (PH3)

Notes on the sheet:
LED
XTAL & RST
Filter

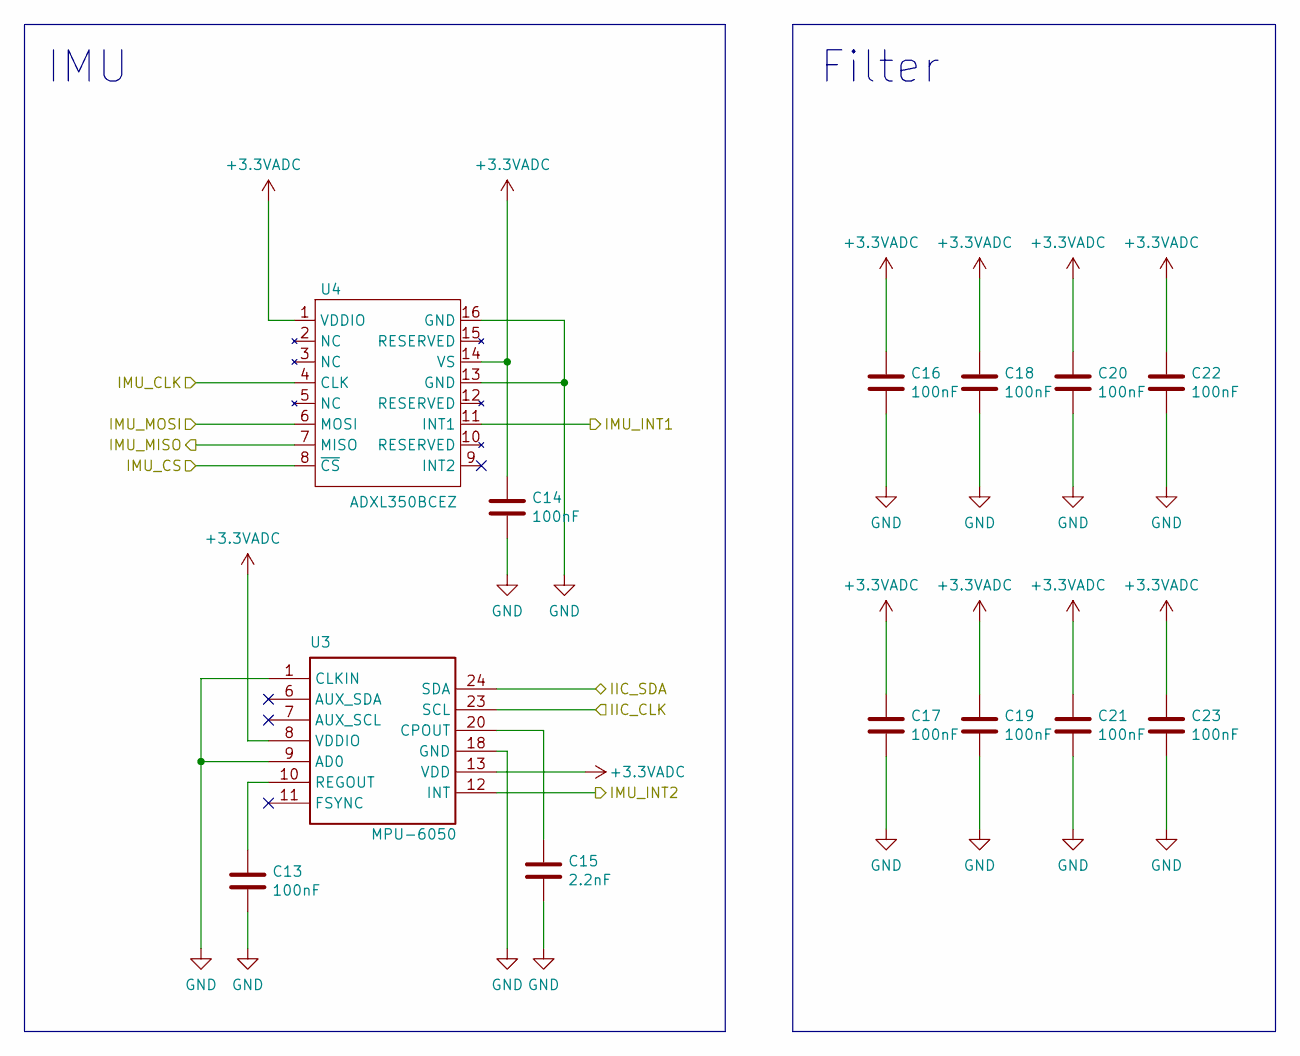
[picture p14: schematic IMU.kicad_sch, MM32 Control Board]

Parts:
C13, C14, C16, C17, C18, C19, C20, C21, C22, C23: 100nF; C_0603_1608Metric
C15: 2.2nF; C_0603_1608Metric
U3: MPU-6050; InvenSense_QFN-24_4x4mm_P0.5mm
U4: ADXL350BCEZ; LGA-16-3.35mm_3.53mm

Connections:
+3.3VADC: C14.1, C16.1, C17.1, C18.1, C19.1, C20.1, C21.1, C22.1, C23.1, U3.8 (VDDIO), U3.13 (VDD), U4.1 (VDDIO), U4.14 (VS); also elsewhere on the board
/Coprocessor/IIC_CLK: U3.23 (SCL); also elsewhere on the board
/Coprocessor/IIC_SDA: U3.24 (SDA); also elsewhere on the board
/Coprocessor/PC6: U3.12 (INT); also elsewhere on the board
/Coprocessor/PC7: U4.11 (INT1); also elsewhere on the board
/Coprocessor/SPI2_CLK: U4.4 (CLK); also elsewhere on the board
/Coprocessor/SPI2_MISO: U4.7 (MISO); also elsewhere on the board
/Coprocessor/SPI2_MOSI: U4.6 (MOSI); also elsewhere on the board
/Coprocessor/SPI2_NSS: U4.8 (~CS); also elsewhere on the board
GND: C13.2, C14.2, C15.2, C16.2, C17.2, C18.2, C19.2, C20.2, C21.2, C22.2, C23.2, U3.1 (CLKIN), U3.9 (AD0), U3.18 (GND), U3.25, U4.13 (GND), U4.16 (GND); also elsewhere on the board
unnamed: C13.1, U3.10 (REGOUT)
unnamed: C15.1, U3.20 (CPOUT)

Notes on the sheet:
IMU
Filter

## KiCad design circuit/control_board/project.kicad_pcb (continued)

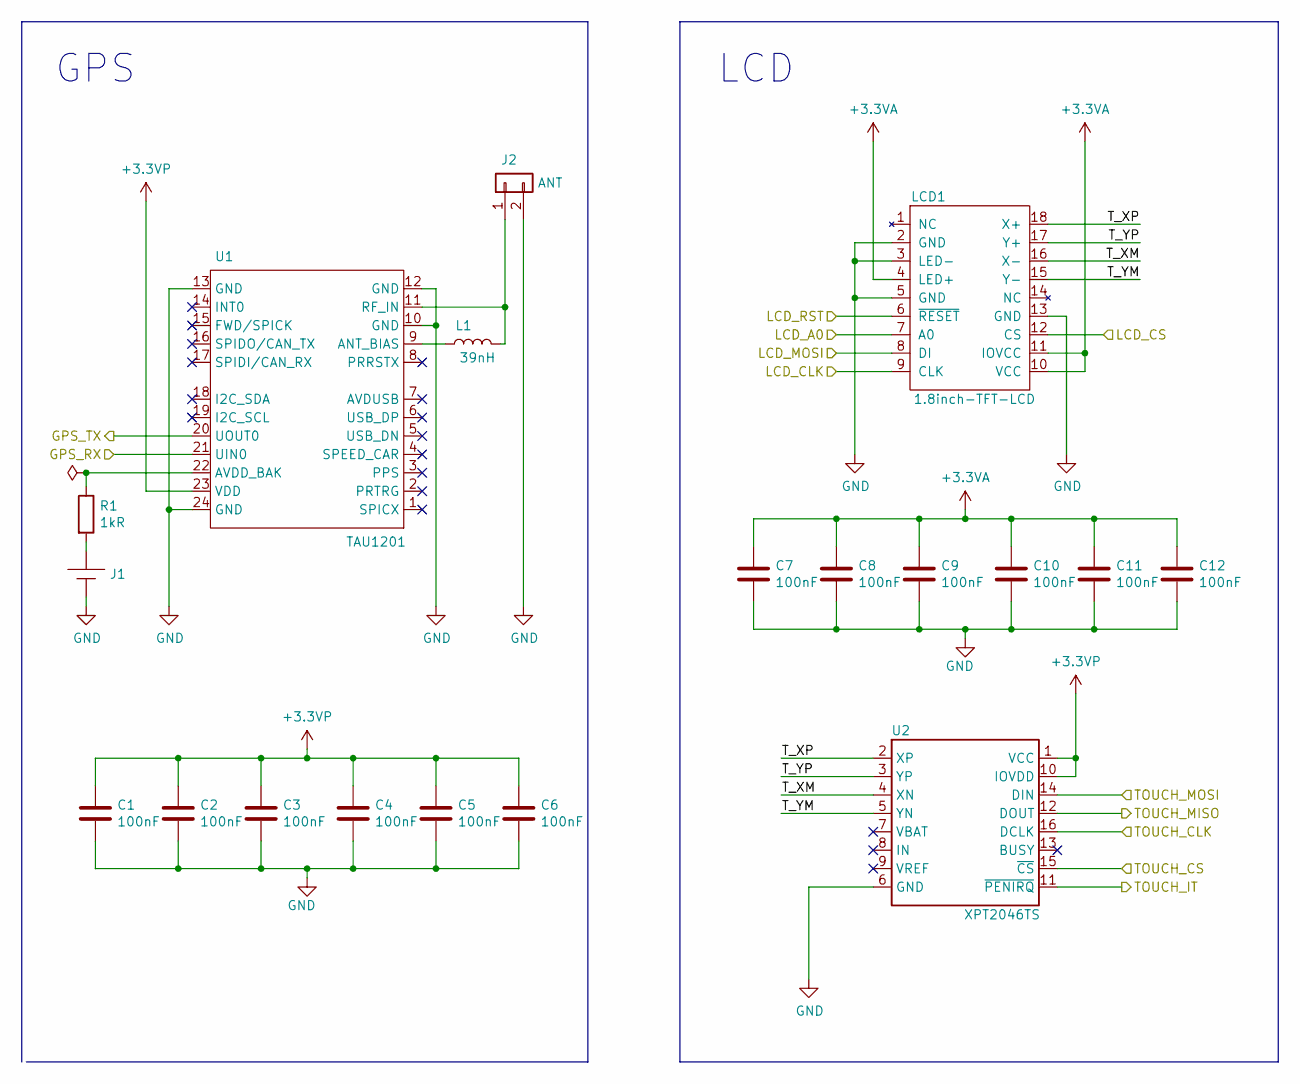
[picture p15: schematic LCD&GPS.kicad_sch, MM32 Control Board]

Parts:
C1, C2, C3, C4, C5, C6, C7, C8, C9, C10, C11, C12: 100nF; C_0603_1608Metric
J1: BAT_CR1220
J2: ANT; SMA_Molex_73251-2200_Horizontal
L1: 39nH; L_0603_1608Metric
LCD1: 1.8inch-TFT-LCD; TFT-LCD1.8inch
R1: 1kR; R_0603_1608Metric
U1: TAU1201; ublox_NEO
U2: XPT2046TS; TSSOP-16_4.4x5mm_P0.65mm

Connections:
+3.3VA: C7.1, C8.1, C9.1, C10.1, C11.1, C12.1, LCD1.4 (LED+), LCD1.10 (VCC), LCD1.11 (IOVCC); also elsewhere on the board
+3.3VP: C1.1, C2.1, C3.1, C4.1, C5.1, C6.1, U1.23 (VDD), U2.1 (VCC), U2.10 (IOVDD); also elsewhere on the board
/LCD&GPS/GPS_RX: U1.21 (UIN0); also elsewhere on the board
/LCD&GPS/GPS_TX: U1.20 (UOUT0); also elsewhere on the board
/LCD&GPS/LCD_A0: LCD1.7 (A0); also elsewhere on the board
/LCD&GPS/LCD_CLK: LCD1.9 (CLK); also elsewhere on the board
/LCD&GPS/LCD_CS: LCD1.12 (CS); also elsewhere on the board
/LCD&GPS/LCD_MOSI: LCD1.8 (DI); also elsewhere on the board
/LCD&GPS/LCD_RST: LCD1.6 (~RESET); also elsewhere on the board
/LCD&GPS/TOUCH_CLK: U2.16 (DCLK); also elsewhere on the board
/LCD&GPS/TOUCH_CS: U2.15 (~CS); also elsewhere on the board
/LCD&GPS/TOUCH_IT: U2.11 (~PENIRQ); also elsewhere on the board
/LCD&GPS/TOUCH_MISO: U2.12 (DOUT); also elsewhere on the board
/LCD&GPS/TOUCH_MOSI: U2.14 (DIN); also elsewhere on the board
/LCD&GPS/T_XM: LCD1.16 (X-), U2.4 (XN)
/LCD&GPS/T_XP: LCD1.18 (X+), U2.2 (XP)
/LCD&GPS/T_YM: LCD1.15 (Y-), U2.5 (YN)
/LCD&GPS/T_YP: LCD1.17 (Y+), U2.3 (YP)
GND: C1.2, C2.2, C3.2, C4.2, C5.2, C6.2, C7.2, C8.2, C9.2, C10.2, C11.2, C12.2, J1.2 (N), J2.2, LCD1.2 (GND), LCD1.3 (LED-), LCD1.5 (GND), LCD1.13 (GND), U1.10 (GND), U1.12 (GND), U1.13 (GND), U1.24 (GND), U2.6 (GND); also elsewhere on the board
unnamed: J1.1, R1.2
unnamed: J2.1, L1.2, U1.11 (RF_IN)
unnamed: L1.1, U1.9 (ANT_BIAS)
unnamed: R1.1, U1.22 (AVDD_BAK)

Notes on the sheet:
GPS
LCD

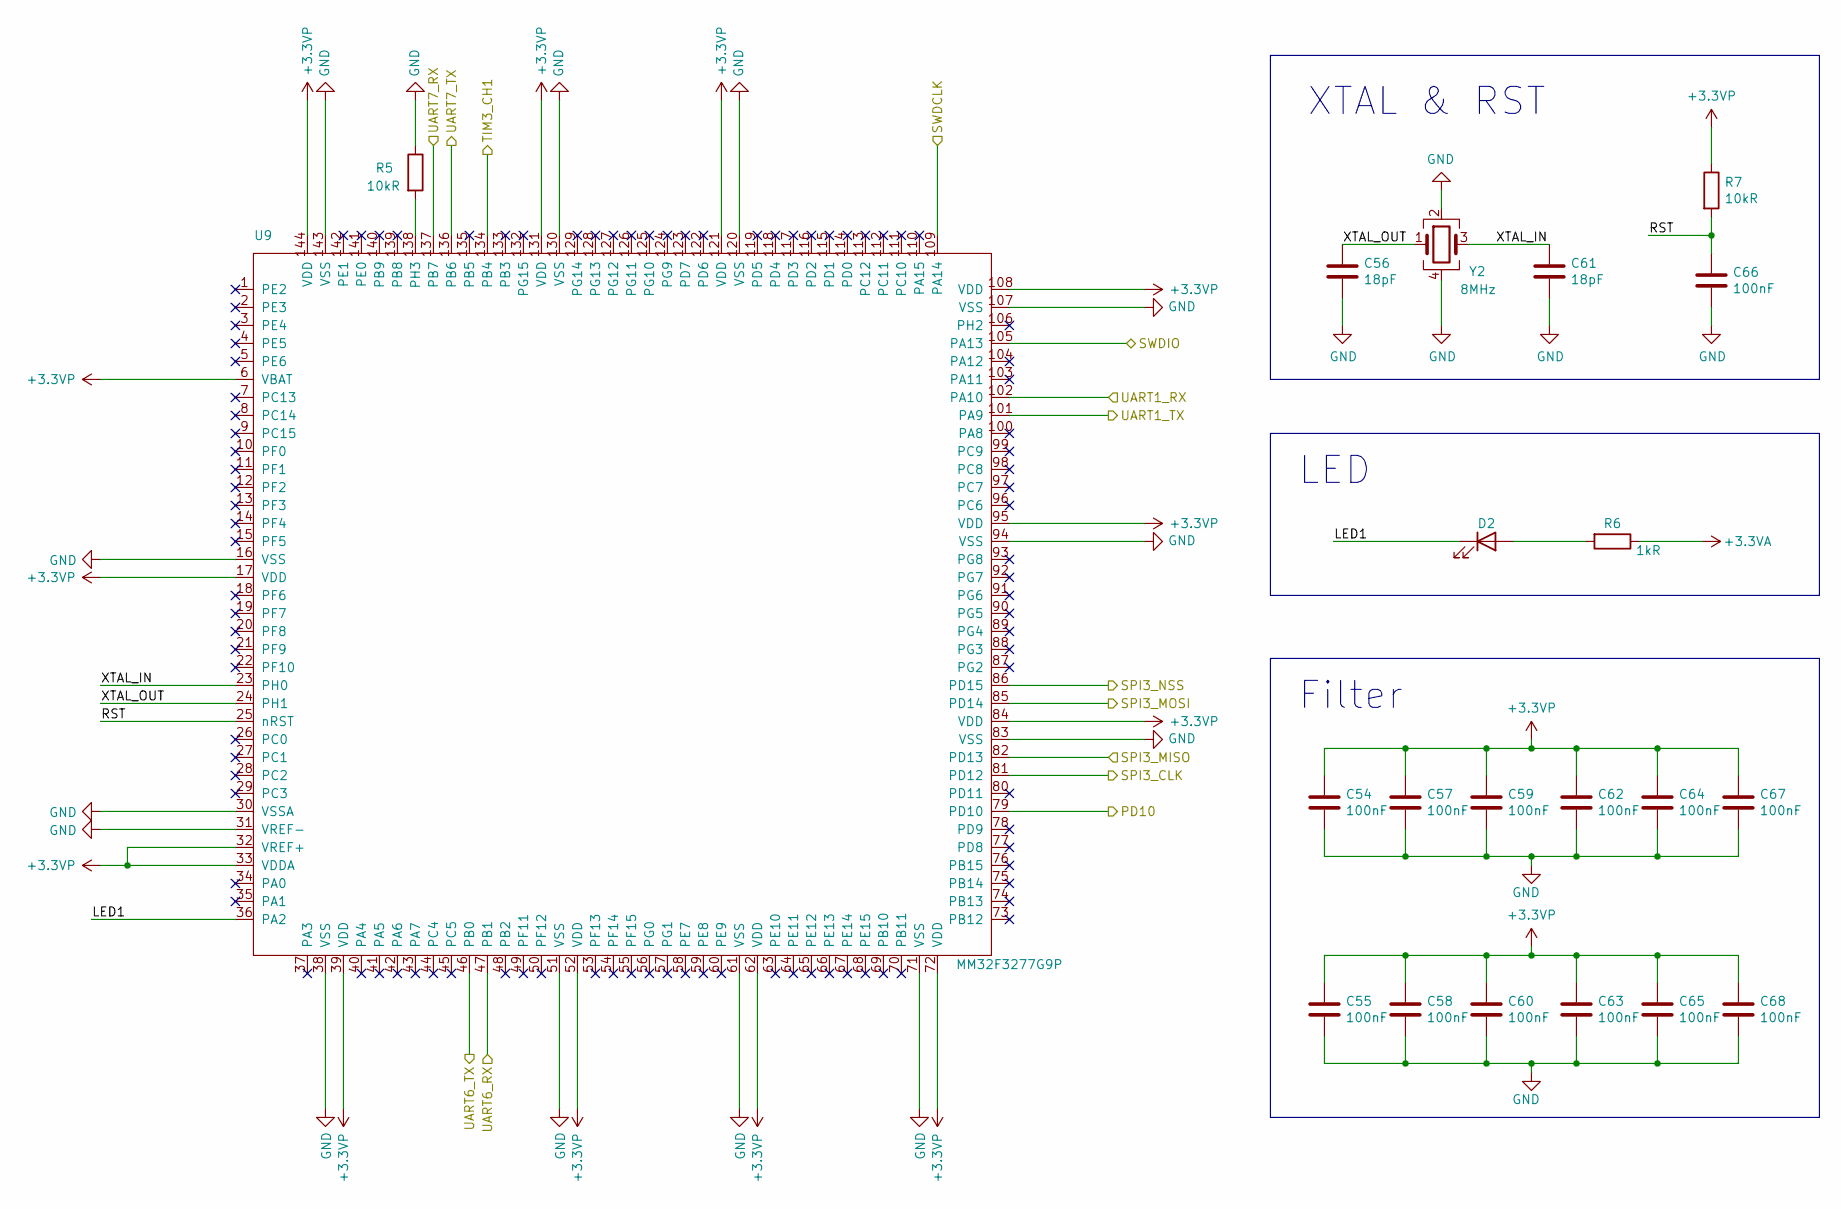
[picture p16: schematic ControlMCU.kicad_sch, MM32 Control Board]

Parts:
C54, C55, C57, C58, C59, C60, C62, C63, C64, C65, C66, C67, C68: 100nF; C_0603_1608Metric
C56, C61: 18pF; C_0603_1608Metric
D2: LED; LED_0603_1608Metric
R5, R7: 10kR; R_0603_1608Metric
R6: 1kR; R_0603_1608Metric
U9: MM32F3277G9P; LQFP-144_20x20mm_P0.5mm
Y2: 8MHz; Crystal_SMD_3225-4Pin_3.2x2.5mm

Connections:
+3.3VA: R6.1; also elsewhere on the board
+3.3VP: C54.1, C55.1, C57.1, C58.1, C59.1, C60.1, C62.1, C63.1, C64.1, C65.1, C67.1, C68.1, R7.1, U9.6 (VBAT), U9.17 (VDD), U9.32 (VREF+), U9.33 (VDDA), U9.39 (VDD), U9.52 (VDD), U9.62 (VDD), U9.72 (VDD), U9.84 (VDD), U9.95 (VDD), U9.108 (VDD), U9.121 (VDD), U9.131 (VDD), U9.144 (VDD); also elsewhere on the board
/Control_MCU/LED1: D2.1 (K), U9.36 (PA2)
/Control_MCU/PD10: U9.79 (PD10); also elsewhere on the board
/Control_MCU/RST: C66.1, R7.2, U9.25 (nRST)
/Control_MCU/SPI3_CLK: U9.81 (PD12); also elsewhere on the board
/Control_MCU/SPI3_MISO: U9.82 (PD13); also elsewhere on the board
/Control_MCU/SPI3_MOSI: U9.85 (PD14); also elsewhere on the board
/Control_MCU/SPI3_NSS: U9.86 (PD15); also elsewhere on the board
/Control_MCU/SWDCLK: U9.109 (PA14); also elsewhere on the board
/Control_MCU/SWDIO: U9.105 (PA13); also elsewhere on the board
/Control_MCU/TIM3_CH1: U9.134 (PB4); also elsewhere on the board
/Control_MCU/UART1_RX: U9.102 (PA10); also elsewhere on the board
/Control_MCU/UART1_TX: U9.101 (PA9); also elsewhere on the board
/Control_MCU/UART6_RX: U9.47 (PB1); also elsewhere on the board
/Control_MCU/UART6_TX: U9.46 (PB0); also elsewhere on the board
/Control_MCU/UART7_RX: U9.137 (PB7); also elsewhere on the board
/Control_MCU/UART7_TX: U9.136 (PB6); also elsewhere on the board
/Control_MCU/XTAL_IN: C61.1, U9.23 (PH0), Y2.3
/Control_MCU/XTAL_OUT: C56.1, U9.24 (PH1), Y2.1
GND: C54.2, C55.2, C56.2, C57.2, C58.2, C59.2, C60.2, C61.2, C62.2, C63.2, C64.2, C65.2, C66.2, C67.2, C68.2, R5.1, U9.16 (VSS), U9.30 (VSSA), U9.31 (VREF-), U9.38 (VSS), U9.51 (VSS), U9.61 (VSS), U9.71 (VSS), U9.83 (VSS), U9.94 (VSS), U9.107 (VSS), U9.120 (VSS), U9.130 (VSS), U9.143 (VSS), Y2.2, Y2.4; also elsewhere on the board
unnamed: D2.2 (A), R6.2
unnamed: R5.2, U9.138 (PH3)

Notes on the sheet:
LED
XTAL & RST
Filter


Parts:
C71: 4.7uF; C_0603_1608Metric
C72: 100nF; C_0603_1608Metric
J4: Conn_01x06; JST_GH_SM06B-GHS-TB_1x06-1MP_P1.25mm_Horizontal
R9, R10: 10kR; R_0603_1608Metric
U11: AT24C02; SOP-8_3.9x4.9mm_P1.27mm

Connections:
+3.3VA: C72.1, R9.1, R10.1, U11.8 (VDD); also elsewhere on the board
+3.3VADC: C71.1, J4.1; also elsewhere on the board
/Compass&Storage/Compass_CLK: J4.5; also elsewhere on the board
/Compass&Storage/Compass_CS: J4.2; also elsewhere on the board
/Compass&Storage/Compass_MISO: J4.4; also elsewhere on the board
/Compass&Storage/Compass_MOSI: J4.3; also elsewhere on the board
/Compass&Storage/EEPROM_SCL: R10.2, U11.6 (SCL); also elsewhere on the board
/Compass&Storage/EEPROM_SDA: R9.2, U11.5 (SDA); also elsewhere on the board
GND: C71.2, C72.2, J4.6, U11.1 (A0), U11.2 (A1), U11.3 (A2), U11.4 (GND), U11.7 (WP); also elsewhere on the board

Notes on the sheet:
EEPROM
Compass


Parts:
C73: 100nF; C_0603_1608Metric
D3: LED; LED_0603_1608Metric
J5: Conn_01x04; SWD_Connector
R11, R12, R13, R14: 10kR; R_0603_1608Metric
R15: 1kR; R_0603_1608Metric
U12: MM32SPIN27PS; LQFP-64_10x10mm_P0.5mm

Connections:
+3.3VADC: J5.1, R12.1, R13.1, R14.1, R15.1, U12.13 (VDDA), U12.32 (VDD), U12.64 (VDD); also elsewhere on the board
/Compass&Storage/Compass_CLK: U12.21 (PA5); also elsewhere on the board
/Compass&Storage/Compass_CS: U12.20 (PA4); also elsewhere on the board
/Compass&Storage/Compass_MISO: U12.18 (PD4); also elsewhere on the board
/Compass&Storage/Compass_MOSI: U12.19 (PD5); also elsewhere on the board
/Coprocessor/IIC_CLK: R13.2, U12.56 (PB4); also elsewhere on the board
/Coprocessor/IIC_SDA: R12.2, U12.55 (PB3); also elsewhere on the board
/Coprocessor/LED1: D3.1 (K), U12.51 (PC10)
/Coprocessor/PC6: U12.37 (PC6); also elsewhere on the board
/Coprocessor/PC7: U12.38 (PC7); also elsewhere on the board
/Coprocessor/RST: C73.1, R14.2, U12.7 (nRST)
/Coprocessor/SPI2_CLK: U12.34 (PB13); also elsewhere on the board
/Coprocessor/SPI2_MISO: U12.35 (PB14); also elsewhere on the board
/Coprocessor/SPI2_MOSI: U12.36 (PB15); also elsewhere on the board
/Coprocessor/SPI2_NSS: U12.33 (PB12); also elsewhere on the board
/Coprocessor/SWDCLK: J5.3, U12.49 (PA14)
/Coprocessor/SWDIO: J5.2, U12.46 (PA13)
/Coprocessor/UART1_RX: U12.43 (PA10); also elsewhere on the board
/Coprocessor/UART1_TX: U12.42 (PA9); also elsewhere on the board
GND: C73.2, J5.4, R11.1, U12.12 (VSSA), U12.31 (VSS), U12.63 (VSS); also elsewhere on the board
unnamed: D3.2 (A), R15.2
unnamed: R11.2, U12.60 (BOOT0)

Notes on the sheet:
LED
RST


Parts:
C74, C75, C76: 100nF; C_0603_1608Metric
D4: LED; LED_0603_1608Metric
P1: USB_C_Plug_USB2.0; USB_C_Receptacle_HRO_TYPE-C-31-M-12
R16: 100kR; R_0603_1608Metric
R17: 4.7kR; R_0603_1608Metric
R18, R19: 10kR; R_0603_1608Metric
U13: GL823K; SSOP-16_3.9x4.9mm_P0.635mm
U14: CH440R; TSSOP-16_4.4x5mm_P0.65mm
U15, U16: CH443K; SOT-363_SC-70-6
U17: MKDV1GCL-AB; LGA-8060_8

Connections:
+3.3VP: R18.1, R19.1, U17.8 (Vin); also elsewhere on the board
+5V: P1.A4 (VBUS), P1.A9 (VBUS), P1.B4 (VBUS), P1.B9 (VBUS), R17.1, U13.10 (5V), U14.16 (VCC), U15.5 (VCC), U16.5 (VCC); also elsewhere on the board
/Control_MCU/PD10: U14.1 (SEL), U15.6 (SEL), U16.6 (SEL); also elsewhere on the board
/Control_MCU/SPI3_CLK: U14.10 (S2C); also elsewhere on the board
/Control_MCU/SPI3_MISO: U14.3 (S2A); also elsewhere on the board
/Control_MCU/SPI3_MOSI: U14.6 (S2B); also elsewhere on the board
/Control_MCU/SPI3_NSS: U14.13 (S2D); also elsewhere on the board
/Flash&USB/CLK: U13.4 (CLK), U14.11 (S1C)
/Flash&USB/CMD: U13.5 (CMD), U14.5 (S1B)
/Flash&USB/DATA0: U13.3 (D0), U14.2 (S1A)
/Flash&USB/DATA1: U13.2 (D1), U16.3 (CH0)
/Flash&USB/DATA2: U13.7 (D2), U15.3 (CH0)
/Flash&USB/DATA3: U13.6 (D3), U14.14 (S1D)
/Flash&USB/GL_DM: P1.A7 (D-), P1.B7 (D-), U13.16 (DM)
/Flash&USB/GL_DP: P1.A6 (D+), P1.B6 (D+), U13.15 (DP)
/Flash&USB/SD_CLK: U14.9 (DC), U17.3 (CLK)
/Flash&USB/SD_CMD: U14.7 (DB), U17.5 (CMD)
/Flash&USB/SD_D0: U14.4 (DA), U17.6 (DAT0)
/Flash&USB/SD_D1: U16.4 (COM), U17.7 (DAT1)
/Flash&USB/SD_D2: U15.4 (COM), U17.1 (DAT2)
/Flash&USB/SD_D3: U14.12 (DD), U17.2 (DAT3)
/Flash&USB/USB_VDD: C74.1, C75.1, C76.1, U13.9 (VDD), U13.13 (VDDA)
GND: C74.2, C75.2, C76.2, P1.A1 (GND), P1.A12 (GND), P1.B1 (GND), P1.B12 (GND), R16.2, U13.1 (VSS), U13.14 (VSS), U14.8 (GND), U14.15 (#EN), U15.2 (GND), U16.2 (GND), U17.4 (GND); also elsewhere on the board
unnamed: D4.1 (K), U13.12 (LED)
unnamed: D4.2 (A), R17.2
unnamed: R16.1, U13.11 (GPIO)
unnamed: R18.2, U15.1 (CH1)
unnamed: R19.2, U16.1 (CH1)

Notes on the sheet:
Flash
Switch
USB Interface

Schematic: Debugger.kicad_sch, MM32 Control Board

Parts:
C69: 10uF; C_0603_1608Metric
C70: 100nF; C_0603_1608Metric
M1: Debugger; Gernic_Debugger
R8: 10kR; R_0603_1608Metric
SW1: SW_DIP_x02; SW_DIP_SPSTx02_Slide_Copal_CHS-02B_W7.62mm_P1.27mm
U10: CH440R; TSSOP-16_4.4x5mm_P0.65mm

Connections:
+5V: C69.1, C70.1, M1.1 (5V), M1.8 (5V), R8.1, U10.16 (VCC); also elsewhere on the board
/Control_MCU/SWDCLK: U10.3 (S2A); also elsewhere on the board
/Control_MCU/SWDIO: U10.6 (S2B); also elsewhere on the board
/Control_MCU/UART1_RX: U10.13 (S2D); also elsewhere on the board
/Control_MCU/UART1_TX: U10.10 (S2C); also elsewhere on the board
/Debugger/DBG_RX: M1.6 (U_TX), U10.9 (DC)
/Debugger/DBG_RX1: U10.11 (S1C); also elsewhere on the board
/Debugger/DBG_TX: M1.7 (U_RX), U10.12 (DD)
/Debugger/DBG_TX1: U10.14 (S1D); also elsewhere on the board
/Debugger/SEL: R8.2, SW1.4, U10.1 (SEL)
/Debugger/SWDCLK: M1.3 (SWDCLK), U10.4 (DA)
/Debugger/SWDCLK1: U10.2 (S1A); also elsewhere on the board
/Debugger/SWDIO: M1.2 (SWDIO), U10.7 (DB)
/Debugger/SWDIO1: U10.5 (S1B); also elsewhere on the board
GND: C69.2, C70.2, M1.4 (GND), M1.5 (GND), SW1.1, U10.8 (GND), U10.15 (#EN); also elsewhere on the board

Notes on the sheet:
Debugger
Switch



Board: 4 copper layers, 95.0 x 50.0 mm, 128 parts (77 on the bottom side), 106 nets.

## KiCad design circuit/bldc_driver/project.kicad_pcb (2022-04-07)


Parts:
C1: 1uF; C_0603_1608Metric
C2, C3, C4: 10uF; C_0603_1608Metric
C7, C8: 100nF; C_0603_1608Metric
D1, D2: LED; LED_0603_1608Metric
J1: Conn_01x04; PinSocket_1x04_P2.54mm_Vertical
R1, R16, R17: 10kR; R_0603_1608Metric
R2, R3, R4, R5, R6, R7: 1kR; R_0603_1608Metric
R8, R9, R10, R11: 100kR; R_0603_1608Metric
R12: 47kR; R_0603_1608Metric
R13, R14: 2kR; R_0603_1608Metric
R15: 40kR; R_0603_1608Metric
U1: MM32SPIN360C; QFN-48-1EP_6x6mm_P0.4mm_EP4.2x4.2mm
U2: REF3025; SOT-23

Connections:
+2V5: R8.2, R9.2, U2.2 (OUT)
+5V: J1.1, R13.1, R14.1, R17.1, U1.3 (VDDIO), U1.9 (VDDA), U1.23 (VDDIO), U2.1 (VCC); also elsewhere on the board
+12V: U1.2 (VCC); also elsewhere on the board
+15V: R15.1; also elsewhere on the board
/Connector/HA: U1.10 (PA0); also elsewhere on the board
/Connector/HB: U1.11 (PA1); also elsewhere on the board
/Connector/HC: U1.12 (PA2); also elsewhere on the board
/Connector/NTC: U1.17 (PA7); also elsewhere on the board
/Controller/HO1: U1.47 (HO1); also elsewhere on the board
/Controller/HO2: U1.43 (HO2); also elsewhere on the board
/Controller/HO3: U1.39 (HO3); also elsewhere on the board
/Controller/IA: R4.2; also elsewhere on the board
/Controller/IB: R5.2; also elsewhere on the board
/Controller/ISUM: R2.2, R3.2, R7.2; also elsewhere on the board
/Controller/LO1: U1.45 (LO1); also elsewhere on the board
/Controller/LO2: U1.41 (LO2); also elsewhere on the board
/Controller/LO3: U1.37 (LO3); also elsewhere on the board
/Controller/PA3: C1.1, R1.2, U1.13 (PA3), U1.35 (PD3/CMP4_INP)
/Controller/PA4: R7.1, U1.14 (PA4/OP1_INP)
/Controller/PA5: R6.2, R12.2, U1.15 (PA5/OP1_INM)
/Controller/PA6: R1.1, R12.1, U1.16 (PA6/OP1_OUT)
/Controller/PB0: R4.1, R8.1, U1.18 (PB0/OP2_INP)
/Controller/PB1: R2.1, R10.2, U1.19 (PB1/OP2_INM)
/Controller/PB2: R10.1, U1.20 (PB2/OP2_OUT)
/Controller/PB10: R11.1, U1.21 (PB10/OP3_OUT)
/Controller/PB11: R3.1, R11.2, U1.22 (PB11/OP3_INM)
/Controller/PB12: R5.1, R9.1, U1.25 (PB12/OP3_INP)
/Controller/PB13: D1.1 (K), U1.26 (PB13)
/Controller/PB15: C8.1, R15.2, R16.1, U1.28 (PB15)
/Controller/RST: C7.1, R17.2, U1.8 (~RST)
/Controller/SWDCLK: J1.2, U1.36 (PA14/SWDCLK)
/Controller/SWDIO: J1.3, U1.33 (PA13/SWDIO)
/Controller/UART1_RX: U1.30 (PA10); also elsewhere on the board
/Controller/UART1_TX: U1.29 (PA9); also elsewhere on the board
/Controller/VS1: C2.2, U1.46 (VS1); also elsewhere on the board
/Controller/VS2: C3.2, U1.42 (VS2); also elsewhere on the board
/Controller/VS3: C4.2, U1.38 (VS3); also elsewhere on the board
GND: C1.2, C7.2, C8.2, D2.1 (K), J1.4, R6.1, R16.2, U1.1 (GND), U1.24 (GND), U1.49 (GND), U2.3 (GND); also elsewhere on the board
unnamed: C2.1, U1.48 (VB1)
unnamed: C3.1, U1.44 (VB2)
unnamed: C4.1, U1.40 (VB3)
unnamed: D1.2 (A), R13.2
unnamed: D2.2 (A), R14.2

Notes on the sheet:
Current Sample
LED
Microcontroller
Debug Port
RST


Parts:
C14: 100nF; C_0603_1608Metric
J5: GH1.25_6P; JST_GH_BM06B-GHS-TBT_1x06-1MP_P1.25mm_Vertical
R36: 10kR; R_0603_1608Metric
U4, U5, U6: 74HC1G126GW; SOT-353_SC-70-5

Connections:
+5V: J5.1, R36.1, U4.1 (OE), U4.5 (VCC), U5.1 (OE), U5.5 (VCC), U6.1 (OE), U6.5 (VCC); also elsewhere on the board
/Connector/HA: U4.4 (Y); also elsewhere on the board
/Connector/HB: U5.4 (Y); also elsewhere on the board
/Connector/HC: U6.4 (Y); also elsewhere on the board
/Connector/MHA: J5.3, U4.2 (A)
/Connector/MHB: J5.4, U5.2 (A)
/Connector/MHC: J5.5, U6.2 (A)
/Connector/NTC: C14.2, J5.2, R36.2; also elsewhere on the board
GND: C14.1, J5.6, U4.3 (GND), U5.3 (GND), U6.3 (GND); also elsewhere on the board

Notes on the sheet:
Motor Connector

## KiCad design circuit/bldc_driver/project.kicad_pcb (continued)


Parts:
J4: MR30; MR30_Vertical
Q1, Q2, Q3, Q4, Q5, Q6: CSD18540Q5B; TDSON-8-1
R21, R22, R26, R27, R32, R33: 33R; R_0603_1608Metric
R23, R24, R28, R29, R34, R35: 10kR; R_0603_1608Metric
R25, R30, R31: 2mR; R_1206_3216Metric

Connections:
+15V: Q1.5 (D), Q3.5 (D), Q5.5 (D); also elsewhere on the board
/Controller/HO1: R32.1; also elsewhere on the board
/Controller/HO2: R26.1; also elsewhere on the board
/Controller/HO3: R21.1; also elsewhere on the board
/Controller/IA: Q6.1 (S), Q6.2 (S), Q6.3 (S), R25.2; also elsewhere on the board
/Controller/IB: Q4.1 (S), Q4.2 (S), Q4.3 (S), R31.2; also elsewhere on the board
/Controller/ISUM: Q2.1 (S), Q2.2 (S), Q2.3 (S), R24.1, R25.1, R29.1, R30.2, R31.1; also elsewhere on the board
/Controller/LO1: R33.1; also elsewhere on the board
/Controller/LO2: R27.1; also elsewhere on the board
/Controller/LO3: R22.1; also elsewhere on the board
/Controller/VS1: J4.3, Q5.1 (S), Q5.2 (S), Q5.3 (S), Q6.5 (D), R34.1; also elsewhere on the board
/Controller/VS2: J4.2, Q3.1 (S), Q3.2 (S), Q3.3 (S), Q4.5 (D), R28.1; also elsewhere on the board
/Controller/VS3: J4.1, Q1.1 (S), Q1.2 (S), Q1.3 (S), Q2.5 (D), R23.1; also elsewhere on the board
GND: R30.1, R35.1; also elsewhere on the board
unnamed: Q1.4 (G), R21.2, R23.2
unnamed: Q2.4 (G), R22.2, R24.2
unnamed: Q3.4 (G), R26.2, R28.2
unnamed: Q4.4 (G), R27.2, R29.2
unnamed: Q5.4 (G), R32.2, R34.2
unnamed: Q6.4 (G), R33.2, R35.2

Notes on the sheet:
MOSFET


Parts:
C5: 4.7uF; C_0603_1608Metric
C6, C15: 1uF; C_0603_1608Metric
C9, C12: 10uF; C_1206_3216Metric
C10, C13: 47uF; C_1206_3216Metric
C11: 100nF; C_0603_1608Metric
J2: XT30; AMASS_XT30U-M_1x02_P5.0mm_Vertical
J3: GH1.25-3P; JST_GH_SM03B-GHS-TB_1x03-1MP_P1.25mm_Horizontal
L1: 4.7uH; L_Bourns-SRN4018
R18: 100kR; R_0603_1608Metric
R19: 140kR; R_0603_1608Metric
R20: 10kR; R_0603_1608Metric
U3: JW5015s; SOT-23-6

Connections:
+5V: C6.2, C15.2; also elsewhere on the board
+12V: C5.2, C12.2, C13.2, L1.2, R19.1; also elsewhere on the board
+15V: C9.2, C10.2, J2.2, R18.1, U3.5 (VIN); also elsewhere on the board
/Controller/UART1_RX: J3.2; also elsewhere on the board
/Controller/UART1_TX: J3.1; also elsewhere on the board
GND: C5.1, C6.1, C9.1, C10.1, C12.1, C13.1, C15.1, J2.1, J3.3, R20.2, U3.2 (GND); also elsewhere on the board
unnamed: C11.1, U3.1 (BST)
unnamed: C11.2, L1.1, U3.6 (SW)
unnamed: R18.2, U3.4 (EN)
unnamed: R19.2, R20.1, U3.3 (FB)

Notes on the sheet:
Power Supply



Board: 4 copper layers, 30.0 x 40.0 mm, 71 parts (42 on the bottom side), 56 nets.

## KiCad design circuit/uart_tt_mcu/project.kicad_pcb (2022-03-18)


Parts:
C1, C3, C4: 100nF; C_0603_1608Metric
C2: 10uF; C_0603_1608Metric
J1: Conn_02x04_Odd_Even; PinHeader_2x04_P1.27mm_Vertical_SMD
P1: USB_C_Plug_USB2.0; USB_C_Receptacle_HRO_TYPE-C-31-M-12
R1, R2, R3, R4: 10kR; R_0603_1608Metric
U1: E220-900T22S
U2, U3: RS0101YH6; SOT-23-6
U4: HX9193; SOT-23-5
U5: CH330N; SOIC-8_3.9x4.9mm_P1.27mm

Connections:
+3V3: C2.1, C3.1, R1.1, R3.1, U1.25 (VCC), U2.1 (VCCA), U3.1 (VCCA), U4.5 (VOUT)
+5V: C1.1, J1.1, J1.2, P1.A4 (VBUS), P1.A9 (VBUS), P1.B4 (VBUS), P1.B9 (VBUS), U2.5 (OE), U2.6 (VCCB), U3.5 (OE), U3.6 (VCCB), U4.1 (VIN), U4.3 (EN), U5.5 (VCC)
/U0_RXD: U2.4 (B), U5.6 (TXD)
/U0_TXD: U3.4 (B), U5.7 (RXD)
/USB_DM: P1.A7 (D-), P1.B7 (D-), U5.2 (UD-)
/USB_DP: P1.A6 (D+), P1.B6 (D+), U5.1 (UD+)
/U_RXD: J1.5, U1.22 (RXD), U2.3 (A)
/U_TXD: J1.3, U1.23 (TXD), U3.3 (A)
GND: C1.2, C2.2, C3.2, C4.2, J1.7, J1.8, P1.A1 (GND), P1.A12 (GND), P1.B1 (GND), P1.B12 (GND), R2.1, R4.1, U1.2 (GND), U1.8 (GND), U1.11 (GND), U1.13 (GND), U1.14 (GND), U1.15 (GND), U1.16 (GND), U1.19 (GND), U1.26 (GND), U2.2 (GND), U3.2 (GND), U4.2 (GND), U5.3 (GND)
unnamed: C4.1, U5.8 (V3)
unnamed: R3.2, R4.2, U1.20 (M0)
unnamed: R1.2, R2.2, U1.21 (M1)

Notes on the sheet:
E220-900T22S
USB TO TTL
PWR



Board: 2 copper layers, 40.0 x 20.0 mm, 15 parts (5 on the bottom side), 12 nets.

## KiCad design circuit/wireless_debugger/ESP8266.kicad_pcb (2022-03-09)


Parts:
C1: 10uF; C_0603_1608Metric
C2: 2.4pF; C_0603_1608Metric
C3, C5, C6, C8, C9, C12, C13, C14, C15, C16, C17: 100nF; C_0603_1608Metric
C4: 1uF; C_0603_1608Metric
C7: 3.0pF; C_0603_1608Metric
C10, C11: 18pF; C_0603_1608Metric
D1: LED; LED_0603_1608Metric
J1: Conn_02x04_Odd_Even; PinHeader_2x04_P1.27mm_Vertical_SMD
J2: Conn_01x03; IPEX 1G
K1, K2: SW_DIP_x01; SW_Push_SPST_NO_Alps_SKRK
L1: 2.2nH; L_0603_1608Metric
P1: USB_C_Plug_USB2.0; USB_C_Receptacle_HRO_TYPE-C-31-M-12
R1: 1kR; R_0603_1608Metric
R2, R4, R5, R6, R9, R10: 10kR; R_0603_1608Metric
R3: 12kR; R_0603_1608Metric
R7: 200R; R_0603_1608Metric
R8: 499R; R_0603_1608Metric
U1: W25Q64; SOIC-8_5.23x5.23mm_P1.27mm
U2: ESP8266EX; ESP8266
U3: HX9193; SOT-23-5
U4: CH330N; SOIC-8_3.9x4.9mm_P1.27mm
Y1: 26MHz; Crystal_SMD_3225-4Pin_3.2x2.5mm

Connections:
+3V3: C1.1, C3.1, C4.1, C5.1, C6.1, C9.1, C12.1, C13.1, C15.1, R2.1, R5.2, R6.2, R9.2, R10.2, U1.8 (VCC), U2.1 (VDDA), U2.3 (VDD3P3), U2.4 (VDD3P3), U2.11 (VDDPST), U2.17 (VDDPST), U2.29 (VDDD), U2.30 (VDDA), U3.5 (VOUT)
+5V: C14.1, J1.1, J1.2, P1.A4 (VBUS), P1.A9 (VBUS), P1.B4 (VBUS), P1.B9 (VBUS), U3.1 (VIN), U3.3 (EN), U4.5 (VCC)
/LED: R1.2, R4.2, U2.13 (MTDO)
/RST: C17.1, K2.2, R9.1, U2.32 (EXT_RSTB)
/SD_CLK: R7.2, U1.6 (CLK)
/SD_CMD: U1.1 (~CS), U2.20 (SD_CMD)
/SD_DATA0: U1.2 (DO(IO1)), U2.22 (SD_DATA0)
/SD_DATA1: U1.5 (DI(IO0)), U2.23 (SD_DATA1)
/SD_DATA2: U1.7 (IO3), U2.18 (SD_DATA2)
/SD_DATA3: U1.3 (IO2), U2.19 (SD_DATA3)
/SWDCLK: J1.6, U2.9 (MTMS)
/SWDIO: J1.4, U2.12 (MTCK)
/U0_RXD: J1.5, U2.25 (U0RXD), U4.6 (TXD)
/U0_TXD: R8.2, U4.7 (RXD)
/UART_TX: J1.3, R10.1, U2.14 (GPIO2)
/USB_DM: P1.A7 (D-), P1.B7 (D-), U4.2 (UD-)
/USB_DP: P1.A6 (D+), P1.B6 (D+), U4.1 (UD+)
GND: C1.2, C2.2, C3.2, C4.2, C5.2, C6.2, C7.2, C8.2, C9.2, C10.2, C11.2, C12.2, C13.2, C14.2, C15.2, C16.2, C17.2, D1.1 (K), J1.7, J1.8, J2.1, J2.2, K1.1, K2.1, P1.A1 (GND), P1.A12 (GND), P1.B1 (GND), P1.B12 (GND), R3.1, R4.1, U1.4 (GND), U2.33 (GND), U3.2 (GND), U4.3 (GND), Y1.2, Y1.4
unnamed: C2.1, J2.3, L1.1
unnamed: C7.1, L1.2, U2.2 (LNA)
unnamed: C8.1, R2.2, U2.7 (CHIP_EN)
unnamed: C10.1, U2.28 (XTAL_IN), Y1.1
unnamed: C11.1, U2.27 (XTAL_OUT), Y1.3
unnamed: C16.1, U4.8 (V3)
unnamed: D1.2 (A), R1.1
unnamed: K1.2, R5.1, U2.15 (GPIO0)
unnamed: R3.2, U2.31 (RES12K)
unnamed: R6.1, R8.1, U2.26 (U0TXD)
unnamed: R7.1, U2.21 (SD_CLK)

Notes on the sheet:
ESP8266 & FLASH
PWR&RST
USB TO TTL



Board: 2 copper layers, 40.0 x 20.0 mm, 39 parts (5 on the bottom side), 29 nets.

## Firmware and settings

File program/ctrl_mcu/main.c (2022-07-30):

/**************************************************************************/ /**
    \file     main.c
    \brief    main function Source File
    \author   Lao·Zhu & ZGL
    \version  V1.6.1
    \date     17. July 2022
 ******************************************************************************/

#include "main.h"

/*! \brief FAT file system structure */
FATFS filesystem;

/*! \brief File system buffer arrays */
static unsigned char fs_buffer[FF_MAX_SS * 4];

/*! \brief Determining whether to perform LQR control */
extern volatile unsigned char lqr_flag;

/*! \brief Motor expect speed */
volatile unsigned short speed = 0;

/*! \brief The nearest reference point to the vehicle */
static volatile unsigned short playground_ind = 0;

/*! \brief Information received from proc_mcu */
extern unsigned int uart6_dma_buffer_1[CTRL_MCU_RECEIVE_AMOUNT];
extern unsigned int uart6_dma_buffer_2[CTRL_MCU_RECEIVE_AMOUNT];

/*! \brief Temperature of the motor */
extern unsigned char temperature;

/*! \brief Messages sent to the brushless driver board */
unsigned int uart7_dma_send_buffer[UART7_DMA_SEND_BUFFER] = {0};

int main(void) {
    /* Initialize systick system clock for time delay */
    delay_config();

    /* Initialize the PWM GPIO for timer3 */
    tim3_pwm_gpio_config();

    /* Initialize other peripherals for communication */
    led_config();
    uart1_config();
    uart6_config();
    uart6_dma_nvic_config();
    uart6_dma_receive_config(uart6_dma_buffer_1, CTRL_MCU_RECEIVE_AMOUNT);
    uart6_dma_set_transmit_buffer(uart6_dma_buffer_1, CTRL_MCU_RECEIVE_AMOUNT);
    uart7_config();
    uart7_dma_sent_config(uart7_dma_send_buffer, UART7_DMA_SEND_BUFFER);

    /* Delay to wait for the radio transmission module to be ready */
    delayms(1000);

    /* Initialize debugger-related structures and print debugging information */
    cm_backtrace_config("CtrlMCU", "1.6.1", "1.6.1");
    debugger_register_variable(dbg_uint32, &global_time_stamp, "time");
    printf("CtrlMCU %s %s %s\r\n", __DATE__, __TIME__, GIT_HASH);
    timer2_config();

    /* Initialize Timer 3 and SPI3 and start PWM output */
    spi3_config();
    delayms(2000);
    timer3_config();

    /* Switch SD card read/write interface to MCU */
    sdcard_switch_device(0);

    /* Try to mount the SD card to the file system */
    FRESULT result = f_mount(&filesystem, "0:", 1);
    if (result == FR_NO_FILESYSTEM) {
        printf("Making FileSystem...\r\n");
        if (f_mkfs("0:", 0, fs_buffer, sizeof(fs_buffer)) == FR_OK) {
            f_setlabel((const TCHAR *) "0:SD");
            printf("Make FileSystem Success\r\n");
        } else {
            printf("Error To Make FileSystem\r\n");
            while (1);
        }
    } else if (result != FR_OK) {
        printf("Error To Mount FileSystem\r\n");
        while (1);
    }
    printf("FileSystem Mount Success!\r\n");

    /* Write the current firmware information and scan files in SD card*/
    fs_write_current_info();
    fs_scan_files("0:");

    /* Define the variables needed to find the closest point at departure */
    static unsigned char find_counter = 0;
    static unsigned short start_point = 0;
    volatile static unsigned short index = 0;

    /* Find the closest reference point to the car at the time of departure */
    while (1) {
        LED1_TOGGLE();
        delayms(500);

        /* Transferring motor temperature information to ProcMCU */
        uart6_sendbyte(temperature);

        /* Determine whether the positioning is stable */
        if (proc_data.distance_east != 0 && lqr_flag == 1) {
            lqr_flag = 0;

            /* Find the nearest reference point to the current point */
            playground_ind = find_index(playground_ind);
            start_point = playground_ind;
            find_counter++;
            if (find_counter > 3)
                break;
            LED1_TOGGLE();
        }
    }

    /* Start control, start the car */
    while (1) {
        /* Ensure that the current positioning information is valid */
        if (proc_data.distance_east != 0) {
            /* 10 cycles of servo control with a 400ms cycle */
            for (unsigned char i = 0; i < 10; i++) {
                while (1) {
                    if (lqr_flag == 1) {
                        lqr_flag = 0;
                        LED1_TOGGLE();

                        /* Load the current information into the structure */
                        basic_status_t current_status = {proc_data.distance_north,
                                                         proc_data.distance_east,
                                                         proc_data.north_angle};

                        /* Find the nearest reference point to the current point */
                        playground_ind = find_index(playground_ind);

                        /* Override the reference point and feed it to the LQR controller to calculate the servo angle */
                        index = playground_ind + OVERRUN_POINT;
                        unsigned char angle = lqr_control(index, current_status);

                        /* Write the servo angle control amount to the comparator */
                        WRITE_REG(TIM3->CCR1, angle);
                        break;
                    }
                }
            }
            /* Set the motor speed, and set the speed to 0 if the end point is reached */
            speed = 23000;
            if (playground_ind > INDEX_NUM - 10)
                speed = 0;

            /* Sending motor speed to the motor driver */
            sdtp_data_transmit_speed(speed, uart7_dma_send_buffer);
            uart7_dma_set_send_buffer(uart7_dma_send_buffer, UART7_DMA_SEND_BUFFER);

            /* Transferring motor temperature information to ProcMCU */
            uart6_sendbyte(temperature);
        }
    }
}

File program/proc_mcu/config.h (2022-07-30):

/**************************************************************************/ /**
    \file     config.h
    \brief    file that stores user configuration macros.
    \author   Lao·Zhu
    \version  V1.6.1
    \date     24. July 2022
 ******************************************************************************/

#ifndef MM32F3277_USER_CONFIG_H_
#define MM32F3277_USER_CONFIG_H_

#include "version.h"

//////////////////////////////////////// System & Debugger Macro ////////////////////////////////////////
/*! \brief Using FreeRTOS */
#define USE_FREERTOS            1
/*! \brief Systick interrupt frequency set to 1kHz */
#define configTICK_RATE_HZ      1000
/*! \brief FreeRTOS Heap Size Set To 32KB */
#define RTOS_HEAP_SIZE          32 * 1024
/*! \brief Debugger variable maximum size set to 12 */
#define VARIABLE_BUFFER_SIZE    12
/*! \brief Not use mdtp protocol to print buffer */
#define DEBUG_USE_PROTOCOL      0
/*! \brief Not use vTaskList to report task info */
#define USE_FREERTOS_REPORT     0
/*! \brief GUI CallBack Function Priority set to 2 */
#define GUI_CALLBACK_PRIO       2
/*! \brief Don't calibrate touch sensor at startup */
#define STARTUP_CALIBRATE       0

//////////////////////////////////////// CMBackTrace Macro ////////////////////////////////////////
/*! \brief Enable bare metal(no OS) platform */
#define CMB_USING_BARE_METAL_PLATFORM
/*! \brief CPU platform type set to Cortex-M3 */
#define CMB_CPU_PLATFORM_TYPE          CMB_CPU_ARM_CORTEX_M3
/*! \brief Enable dump stack information */
#define CMB_USING_DUMP_STACK_INFO
/*! \brief Language of print information set as English */
#define CMB_PRINT_LANGUAGE             CMB_PRINT_LANUUAGE_ENGLISH


//////////////////////////////////////// Interrupt Priority ////////////////////////////////////////
/*! \brief Variable scanner timer interrupt priority set to 5 */
#define TIM2_PRIORITY           5
/*! \brief PC debugger receive interrupt priority set to 3 */
#define UART1_PRIORITY          3
/*! \brief ReadMCU data receive interrupt priority set to 2 */
#define UART2_DMA_PRIORITY      2
/*! \brief GNSS receive interrupt priority set to 2 */
#define UART3_DMA_PRIORITY      2
/*! \brief Debugger send DMA interrupt priority set to 4 */
#define UART1_DMA_PRIORITY      4
/*! \brief LCD data transmit interrupt priority set to 6 */
#define SPI3_DMA_PRIORITY       6
/*! \brief Touch sensor interrupt priority set to 5 */
#define EXTI4_PRIORITY          5
/*! \brief ControlMCU data receive interrupt priority set to 4 */
#define UART4_PRIORITY          4
/*! \brief Power board data receive interrupt priority set to 5 */
#define UART6_PRIORITY          5


//////////////////////////////////////// Peripherals Speed ////////////////////////////////////////
#define UART1_BAUDRATE          115200
#define UART2_BAUDRATE          115200
#define UART3_BAUDRATE          115200
#define UART4_BAUDRATE          115200
#define UART6_BAUDRATE          115200

#define IIC1_SPEED              400000

#endif  // MM32F3277_USER_CONFIG_H_

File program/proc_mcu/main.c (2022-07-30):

/**************************************************************************/ /**
    \file     main.c
    \brief    main function Source File
    \author   Lao·Zhu & ZGL
    \version  V1.6.1
    \date     24. July 2022
 ******************************************************************************/

#include "main.h"

unsigned char pc_connect_flag = 0;

/*! \brief Maximum speed of motor detected by brushless driver board */
float statistic_max_speed = 0;

/*! \brief Maximum current detected by the power supply board */
float statistic_max_current = 0;

/*! \brief Battery Current */
extern unsigned char battery_current;

/*! \brief Store to determine if its own position is the temperature */
extern unsigned int temp_stable[100][2];

/*! \brief UART2 receive buffer 1 */
extern unsigned int packages_to_be_unpacked_1[READ_MCU_AMOUNT];

/*! \brief Data after packet sealing */
unsigned int proc_to_ctrl_package[PROC_MCU_SEND_AMOUNT] = {0};

/*! \brief Data before packet sealing */
unsigned int proc_to_ctrl_buffer[4] = {0};

/*! \brief The state volume after Kalman fusion */
kalman_data_t kalman_data = {0};

/*! \brief Kalman structure of v */
kalman_filter_t kalman_v = {0};

/*! \brief Kalman structure of distance_north */
kalman_filter_t kalman_distance_north = {0};

/*! \brief Kalman structure of distance_east */
kalman_filter_t kalman_distance_east = {0};

//////////////////////////////////// Task Handler ////////////////////////////////////
TaskHandle_t led_taskhandler;
TaskHandle_t gui_taskhandler;
TaskHandle_t touch_taskhandler;
TaskHandle_t fusion_taskhandler;
TaskHandle_t initialize_taskhandler;
void touchscan_task(void *parameters);
void guiupdate_task(void *parameters);
void ledblink_task(void *parameters);
void fusion_task(void *parameters);
void initialize_task(void *parameters);

EventGroupHandle_t touch_event = NULL;
QueueHandle_t touch_point_queue;

int main(void) {
    xTaskCreate(initialize_task, "initialize", 1024, NULL, 1,
                &initialize_taskhandler);
    vTaskStartScheduler();
    return 0;
}

//////////////////////////////////////// Tasks ////////////////////////////////////////
void initialize_task(void *parameters) {
    (void) parameters;
    delay_config();
    led_config();
    iic1_config();
    at24c02_readparams();
    spi2_config();
    spi3_config();
    uart1_config();
    uart2_config();
    uart2_dma_nvic_config();
    uart2_dma_receive_config(packages_to_be_unpacked_1, uart2_dma_buffer_size);
    uart2_dma_set_transmit_buffer(packages_to_be_unpacked_1, uart2_dma_buffer_size);
    uart4_config();
    uart6_config();
    xpt2046_gpio_config();
    cm_backtrace_config("ProcMCU", "1.6.1", "1.6.1");
    gui_config();
    delayms(2000);
    uart3_config();
    gps_config();
#if STARTUP_CALIBRATE == 1
    xpt2046_calibrate();
    at24c02_saveparams();
#endif

    debugger_register_variable(dbg_uint32, &global_time_stamp, "time");
    printf("ProcMCU %s %s %s\r\n", __DATE__, __TIME__, GIT_HASH);
    timer2_config();

    xTaskCreate(fusion_task, "sensor_fusion", 1024, NULL, 4,
                &fusion_taskhandler);
    xTaskCreate(ledblink_task, "led_blink", 1024, NULL, 2,
                &led_taskhandler);
    xTaskCreate(guiupdate_task, "gui_update", 2048, NULL, 2,
                &gui_taskhandler);
    xTaskCreate(touchscan_task, "touch_scan", 128, NULL, 2,
                &touch_taskhandler);
    vTaskDelete(NULL);
}

void fusion_task(void *parameters) {
    (void) parameters;
    kalman_config_v(&kalman_v);
        status_V:
    while (gps_rmc.status == 'V') {
        delayms(20);
        proc_to_ctrl_buffer[0] = 0;
        proc_to_ctrl_buffer[1] = 0;
        proc_to_ctrl_buffer[2] = 0;
        proc_to_ctrl_buffer[3] = 0;
        precossing_proc_to_control(proc_to_ctrl_package, proc_to_ctrl_buffer);
        for (unsigned char i = 0; i < PROC_MCU_SEND_AMOUNT; i++) {
            uart3_sendbyte(proc_to_ctrl_package[i]);
        }
    }
    unsigned char stable_flag = 0;
    while (stable_flag == 0) {
        for (unsigned short i = 0; i < STABLE_NUM; i++) {
            unsigned int same_counter = 0;
            for (unsigned short j = i + 1; j < STABLE_NUM; j++) {
                if (temp_stable[j][0] == 0)
                    break;
                if (temp_stable[i][0] == temp_stable[j][0] && temp_stable[i][1] == temp_stable[j][1])
                    same_counter++;
            }
            if (same_counter > 20) {
                stable_flag = 1;
                break;
            }
        }
        delayms(200);
    }
    kalman_config_distance(&kalman_distance_north, neu.north_distance);
    kalman_config_distance(&kalman_distance_east, neu.east_distance);
    unsigned int last_glbal_time_stamp = global_time_stamp - 21;
    while (1) {
        float dt = (float) (global_time_stamp - last_glbal_time_stamp) * 0.001f;
        last_glbal_time_stamp = global_time_stamp;
        if (gps_rmc.status == 'V')
            goto status_V;

        sensor_unit_conversion();
        float last_output_v = kalman_data.v;
        kalman_data.v = kalman_update(&kalman_v, neu.v, neu.acceleration, dt);
        kalman_data.v = kalman_data.v * 0.3f + 0.7f * last_output_v;
        statistic_max_speed = kalman_data.v > statistic_max_speed ? kalman_data.v : statistic_max_speed;

        kalman_v.gps_valid_flag = 1;
        coordinate_system_transformation_kalman_v(small_packets.north);
        kalman_data.distance_north = kalman_update(&kalman_distance_north, neu.north_distance,
                                                   neu.north_v, dt);
        kalman_data.distance_east = kalman_update(&kalman_distance_east, neu.east_distance,
                                                  neu.east_v, dt);

        proc_to_ctrl_buffer[0] = *((unsigned int *) (&kalman_data.distance_north));
        proc_to_ctrl_buffer[1] = *((unsigned int *) (&kalman_data.distance_east));
        proc_to_ctrl_buffer[2] = *((unsigned int *) (&small_packets.north));
        proc_to_ctrl_buffer[3] = *((unsigned int *) (&kalman_data.v));
        precossing_proc_to_control(proc_to_ctrl_package, proc_to_ctrl_buffer);
        for (unsigned char i = 0; i < PROC_MCU_SEND_AMOUNT; i++)
            uart4_sendbyte(proc_to_ctrl_package[i]);

        statistic_max_current =
            (float) battery_current > statistic_max_current ? (float) battery_current : statistic_max_current;

        delayms(39);
    }
}
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

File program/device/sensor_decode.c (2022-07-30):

/**************************************************************************/ /**
    \file       sensor_decode.c
    \brief      sensor_decode function Source File
    \author     ZGL
    \version    V1.6.1
    \date       24. July 2022
******************************************************************************/

#include "sensor_decode.h"
#include "verification.h"

/*! \brief Integral amount of processed sensors */
decode_fixed_sum small_packets_sum = {0};

/*! \brief Processed sensor information */
decode_fixed small_packets = {0};

/*! \brief Sensor raw data and matrix associated with geomagnetic correction */
decode_debug debug_data = {0};

/*! \brief The amount of state of the car */
volatile decode_proc proc_data = {0};

volatile unsigned char lqr_flag = 0;

/*!
    \brief      Packets with fixed data length
    \param[out] packets: Processes packets as long as they are sent through the serial port
    \param[in]  buffer: Data to be sent,includes 5 short type variables and a check digit
*/
void precossing_proc_to_control(unsigned int packets[PROC_MCU_SEND_AMOUNT], const unsigned int *buffer) {
    /* Packet header */
    packets[0] = 0xff;

    /* Adjustment bits for the first 8 information bytes */
    packets[PROC_MCU_SEND_AMOUNT - 4] = 0x00;

    /* Adjustment bits for the last 8 information bytes */
    packets[PROC_MCU_SEND_AMOUNT - 3] = 0x00;

    FLOAT_SPLIT_CHAR(1, 0);
    FLOAT_SPLIT_CHAR(5, 1);
    FLOAT_SPLIT_CHAR(9, 2);
    FLOAT_SPLIT_CHAR(13, 3);

    /* Adjust the bits, from high to low, each bit corresponds to one byte of data, if it is 1,
     * then it means the corresponding data is 0xff */
    for (unsigned char i = 1; i < 9; ++i) {
        if (packets[i] == 0xff) {
            packets[i] = 0x00;
            packets[PROC_MCU_SEND_AMOUNT - 4] |= 0x80 >> (i - 1);
        }
    }
    for (unsigned char i = 9; i < 17; ++i) {
        if (packets[i] == 0xff) {
            packets[i] = 0x00;
            packets[PROC_MCU_SEND_AMOUNT - 3] |= 0x80 >> (i - 9);
        }
    }

    /* Check digit */
    packets[PROC_MCU_SEND_AMOUNT - 2] = verification_crc8(&packets[1], PROC_MCU_SEND_AMOUNT - 3);

    /* Packet tail */
    packets[PROC_MCU_SEND_AMOUNT - 1] = 0xff;
}

/*!
    \brief      Solving packets with fixed data length
    \param[out]  packets: Packets to be solved. Excluding the head and tail of the package
    \note       The package to be solved does not contain the head and tail parts of the package
*/
void unpacking_proc_to_control(unsigned int packets[PROC_MCU_SEND_AMOUNT - 2]) {
    unsigned int temp;
    volatile short checksum = verification_crc8((unsigned int *) packets, PROC_MCU_SEND_AMOUNT - 3);
    proc_data.checksum = (short) packets[PROC_MCU_SEND_AMOUNT - 3];
    if (checksum != proc_data.checksum) return;

    /* Adjustment bits restore the original data, and the order of the checksum can not be changed,
     * because the packet is first counted checksum, and then calculate the adjustment bits */
    for (unsigned char i = 0; i < 8; ++i)
        if (packets[PROC_MCU_SEND_AMOUNT - 5] & (0x80 >> i))
            packets[i] = 0xff;
    for (unsigned char i = 8; i < 16; ++i)
        if (packets[PROC_MCU_SEND_AMOUNT - 4] & (0x80 >> i))
            packets[i] = 0xff;

    /* If you are sending a float type,
     * you must first convert it to an unsigned int address and pass it in */
    DECODE_TO_FLOAT(proc_data.distance_north, 0)
    DECODE_TO_FLOAT(proc_data.distance_east, 4)
    DECODE_TO_FLOAT(proc_data.north_angle, 8)
    DECODE_TO_FLOAT(proc_data.v, 12)

    lqr_flag = 1;
}

/*!
    \brief      Solving packets with fixed data length
    \param[in]  packets: Packets to be solved
    \note       The package to be solved does not contain the head and tail parts of the package
*/
void unpacking_fixed_length_data(unsigned int packets[10]) {
    short checksum = verification_crc8((unsigned int *) packets, 9);
    small_packets.checksum = (short) packets[9];
    if (checksum != small_packets.checksum) return;

    /* If you are sending a float type,
     * you must first convert it to an unsigned int address and pass it in */
    for (unsigned char i = 0; i < 8; ++i)
        if (packets[8] & (0x80 >> i))
            packets[i] = 0xff;

    small_packets.north = (float) ((short) (packets[0] | (((short) packets[5] & 0xf0) << 4))) / 10.0f;
    small_packets.chebyshev_north = (float) ((short) (packets[1] | (((short) packets[5] & 0x0f) << 8))) / 10.0f;
    small_packets.ax = (short) (packets[2] | (((short) packets[6] & 0xf0) << 4));
    small_packets.ay = (short) (packets[3] | ((short) (packets[6] & 0x0f) << 8));
    small_packets.az = (short) (packets[4] | ((short) (packets[7] & 0xf0) << 4));

    /* Unpack the data first, then go to the sensor 3-axis information minus 2048 */
    small_packets.ax -= 2048;
    small_packets.ay -= 2048;
    small_packets.az -= 2048;

    /* small_packets.chebyshev_north: it actually points south and should be corrected to north */
    small_packets.chebyshev_north += 180;
    small_packets.chebyshev_north = (small_packets.chebyshev_north > 360.0f) ? (small_packets.chebyshev_north - 360)
                                                                             : small_packets.chebyshev_north;
    small_packets.north += 180;
    small_packets.north = (small_packets.north > 360.0f) ? (small_packets.north - 360) : small_packets.north;

    small_packets_sum.ay += (float) small_packets.ay;

    small_packets_sum.num++;
}

/*!
    \brief      Packets with variable data length
    \param[out] packets: Processes packets as long as they are sent through the serial port
*/
void unpacking_variable_length_data(unsigned int *packets) {
    unsigned short checksum = verification_crc16((unsigned int *) packets, 64);
    DECODE_TO_SHORT(debug_data.checksum, 64)
    if (checksum != debug_data.checksum) return;

    DECODE_TO_INT(debug_data.mag_x, 0)
    DECODE_TO_INT(debug_data.mag_y, 4)
    DECODE_TO_INT(debug_data.mag_z, 8)
    DECODE_TO_INT(debug_data.offset_x, 12)
    DECODE_TO_INT(debug_data.offset_y, 16)
    DECODE_TO_INT(debug_data.offset_z, 20)
    DECODE_TO_INT(debug_data.diag_x, 24)
    DECODE_TO_INT(debug_data.diag_y, 28)
    DECODE_TO_INT(debug_data.diag_z, 32)
    DECODE_TO_INT(debug_data.offdiag_x, 36)
    DECODE_TO_INT(debug_data.offdiag_y, 40)
    DECODE_TO_INT(debug_data.offdiag_z, 44)
    DECODE_TO_INT(debug_data.residual, 48)
    DECODE_TO_INT(debug_data.step_length, 52)
    DECODE_TO_SHORT(debug_data.num, 56)
    DECODE_TO_SHORT(debug_data.ax, 58)
    DECODE_TO_SHORT(debug_data.ay, 60)
    DECODE_TO_SHORT(debug_data.az, 62)
}

#ifdef IS_CONTROL_MCU
static unsigned char status = 0;
static unsigned int package_buffer[80];
static unsigned char package_counter = 0;
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

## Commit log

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2021-11-14 The FFT algorithm code is added, and the floating-point operation and naming in the code have not been optimized.
    [Doxygen.cfg]
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2021-11-22 Improve the minimum system circuit of the microcontroller by adding two LEDs and a keypad. Pin out the debug pins of the microcontroller.
    [1_Power.sch, 2_MCU.sch, 3_IMU.sch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]
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2021-11-25 Added the debugger's schematic library and improved the circuit of the power section.
    [1_Power.sch, 2_MCU.sch, 3_IMU.sch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]
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2021-11-27 Adjust the schematic layout and add annotations to make the schematic more beautiful.
    [1_Power.sch, 3_IMU.sch]
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2021-11-29 Add the battery voltage detection circuit and complete the circuit connection of XPT2046.
    [1_Power.sch, 4_Connector.sch, project.sch]
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2021-11-30 Assign general-purpose GPIO pins to the LCD. Add annotations to the Connector subdiagram. Label the component markers.
    [1_Power.sch, 2_MCU.sch, 3_IMU.sch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]
2021-11-30 Add packages for standard components and set the basic rules and layers of the PCB.
    [1_Power.sch, 2_MCU.sch, 3_IMU.sch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]
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2021-12-01 Eliminate design rule errors in schematics.
    [1_Power.sch, 2_MCU.sch, 3_IMU.sch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]
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2021-12-02 Fix the problem that Doxygen does not recognize the files. Direct the callback function of serial port 1 to the reception of medium capacity transceiver protocol.
    [Doxygen.cfg]
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2021-12-05 Add copper laying for high power areas and complete small parts of wiring.
    [project.kicad_pcb]
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2021-12-06 Update the PCB file and Gerber file to change the over hole less than 0.4mm to 0.45mm.
    [project-Bottom_Cu.gbr, project-Bottom_Mask.gbr, project-Bottom_Paste.gbr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]
2021-12-09 Correction de l'absence de permission pour la commande ldconfig
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2021-12-12 A serious problem was found: copper laying overlap caused a short circuit, fix this problem.
    [project.kicad_pcb]
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2021-12-13 Fix the problem that printf sending information through debugging will miss the last byte in the package.
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2021-12-21 Modify the circuit to modify the electronic switch section to disconnect via microcontroller control.
    [1_Power.sch, 2_MCU.sch, 3_IMU.sch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]
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2021-12-24 Optimized the problem of floating point precision loss
    [main.c]
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2022-01-01 Added decoding of pmc in gps Solved the problem of checksum calculation error Unit test passed
    [main.c]
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2022-01-15 Add GPS initialization and wrap with define Modify some inappropriate or wrong naming
    [main.c, uart.c]
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2022-01-16 Basically finished all the design of the schematic and selected the package for the components.
    [ControlMCU.kicad_sch, Debugger.kicad_sch, IMU.kicad_sch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]
2022-01-17 State machine to resolve truncated gps packets due to DMA reads
    [gps.c]
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2022-01-17 Eliminates errors when compiling Control targets, standardizes code and removes useless code.
    [dma.c, gps.c, main.c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]
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2022-01-18 Slightly optimized part of the code, fixed some may lead to errors
    [dma.c]
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2022-01-18 Solved the problem of wrong decoding of int16 type in debugging tool.
    [main.c]
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2022-01-19 Modify the Doxygen configuration file to adapt it to the current application to generate documentation.
    [Doxygen.cfg]
2022-01-19 dma.h fix a small error
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2022-01-19 Solved the problem of UART1 using DMA to transfer Debug information. But not yet tested for stability.
    [dma.c, main.c, mm32f3x_it.c]
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2022-01-20 Related initialization of SPI1 Problems arise: PB3 and PB4 need to be modified for remapping to work, but MM32 does not have the relevant registers and library functions, and there is no explanation 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
    [gpio.c, main.c, spi.c]
2022-01-20 Removed or commented out content that would cause unit tests to report errors The mdtp_data_transmit() function is just commented out, but not corrected in the unit test to make it workwork, but MM32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
    [main.c]
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2022-02-06 Modify the method of solving Riccati equation, no longer use ulapack matrix operation library.
    [main.c]
2022-02-07 Attempted to fix part of the ADIS16470 read issue.
    [spi.c]
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2022-02-07 Modify the circuit diagram of the GPS to swap the pin order of the serial port. Add borders to the Compass schematic.
    [Compass&Storage.kicad_sch, LCD&GPS.kicad_sch]
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2022-02-09 Switched the GPS serial port location over and updated the PCB file.
    [Compass&Storage.kicad_sch, ControlMCU.kicad_sch, Debugger.kicad_sch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]
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2022-02-20 Modify the ESP8266 circuit and swap the SPI line sequence.
    [ESP8266.kicad_pcb, ESP8266.kicad_sch]
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2022-02-23 Stagger the DMA of LCD swipe with the transmission DMA of UART1 to prevent mutual interference.
    [dma.c, main.c, mm32f3x_it.c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]
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2022-02-25 AHRS fusion sensor, fusion to get the roll angle is not accurate, the other two angles are more accurate, but the fusion of geomagnetic poles is not effective, can not correct the error caused by the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
    [main.c]
2022-02-26 Modified part of the warning and error, the rest of the warning is indifferent
    [main.c]
2022-02-26 Geomagnetic technology ellipsoid correction Initialize the DR pins of imu Fix a code writing error in part of the ahrs_imu algorithm Add template for continuous sensor reading in adis16740.c
    [gpio.c, main.c, pin.h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]
2022-02-26 Reorganize the code of the riccati solver and add a configuration file using DAP-Link.
    [board_daplink.cfg]
2022-02-26 Geomagnetic pole correction detection with matlab
    [main.c]
2022-02-26 Detecting geomagnetic pole corrections with matlab to obtain accurate stretch and zero bias matrices
    [main.c]
2022-02-26 Detect geomagnetic pole correction with matlab to get the most accurate stretch matrix and zero bias matrix possible
    [main.c]
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2022-02-28 Fixed incorrectly passed parameters in Kalman's algorithm Bug in floating point to integer operation
    [main.c]
2022-02-28 Modified the circuitry of the main control board to add a microcontroller for reading information from the magnetometer and IMU. Modified the SPI connection port of the Process MCU.
    [Compass&Storage.kicad_sch, ControlMCU.kicad_sch, Coprocessor.kicad_sch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]
2022-02-28 Add clear button on tools, but something wrong.
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2022-03-02 Update the main control board schematic and replace the magnetometer with RM3100.
    [Compass&Storage.kicad_sch, ControlMCU.kicad_sch, Coprocessor.kicad_sch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]
2022-03-02 Modify and complete the circuit schematic to make the interface easier to wire.
    [Compass&Storage.kicad_sch, ControlMCU.kicad_sch, Coprocessor.kicad_sch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]
2022-03-02 Complete PCB layout wiring, screen printing adjustment. But not yet checked the circuit.
    [project.kicad_pcb]
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2022-03-04 Coordinate system transformed to NEU, sensor units transformed to international units Solve the problem of confusing information in the initial moment
    [main.c]
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2022-03-05 Modified the font color of the variable table, added the Clear button but it causes the program to flash, haven't found the problem yet.
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2022-03-06 Modify error message and mag calibrate fitness tolerance.
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2022-03-08 Modify all the correction algorithms in mag_calibrate to float type variables for calculation.
    [main.c]
2022-03-08 Verify the feasibility of geomagnetometer correction debug...
    [main.c]
2022-03-08 Verify the feasibility of geomagnetometer correction success
    [main.c]
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2022-03-09 Change the ceramic antenna of wireless debugger to IPEX terminal and external antenna.
    [ESP8266.kicad_pcb, ESP8266.kicad_sch]
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2022-03-13 Correction of the zero offset of the angular velocity meter
    [main.c]
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2022-03-17 Complete the migration of some hardware for the new main control board.
    [board_daplink.cfg]
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2022-03-19 Rolled back the AT24C02 code to use hardware IIC operation, but there was a problem reading and writing some bytes.
    [at24c02.c, iic.c, main.c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]
2022-03-19 Implementation of serial link layer protocols Joint debugging with ProcessMCU to ensure correct reading of accelerometer data and true north angle
    [main.c, mm32f3x_it.c, sensor_decode.c]
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2022-03-19 Divides the LCD display, key detection and LED flip into subtasks.
    [config.h, gpio.c, main.c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]
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2022-03-20 Fixed GPS reception anomaly
    [gps.c, main.c]
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2022-03-20 Ported gui button display related programs and fixed the display color issue.
    [main.c]
2022-03-20 Fixed the problem of fusion process creation failure Fixed the error of calculating distance by GPS latitude and longitude Added the function to calculate acos Bebug
    [main.c]
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2022-03-21 Modify the process stack size to avoid under-allocated memory.
    [main.c]
2022-03-21 Solved the problem of keystroke GUI response.
    [main.c]
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2022-03-24 Modify the scheme of brushless motor driver board to reduce the use of resistors and capacitors to reduce the size of the circuit.
    [Driver.kicad_sch, connector.kicad_sch, controller.kicad_sch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]
2022-03-25 Replace the Kalman filter with a chebyshev filter
    [main.c, sensor_decode.c]
2022-03-25 Fixed the issue of array out-of-bounds in unit tests. Modify the weighting matrix of LQR to weighted values.
    [main.c]
2022-03-25 Some components in the six-step commutation brushless drive were modified to achieve a smaller size.
    [Driver.kicad_sch, controller.kicad_sch, project.kicad_sch]
2022-03-25 Replace all floating point operations in riccati_solver with inline assembly
    [main.c]
2022-03-26 Ported the algorithm for geomagnetometer correction to the coprocessor and wrote the associated reception program in the procMCU
    [config.h, main.c, sensor_decode.c]
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2022-03-26 Complete the design of BLDC Driver PCB and export the interactive BOM.
    [project.kicad_pcb]
2022-03-27 Control coprocessor correction geomagnetometer with gui virtual key implementation Implementing flash read/write
    [main.c]
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2022-03-28 Modify the main control board schematic, replace the IMU device and remove the isolation module.
    [Compass&Storage.kicad_sch, ControlMCU.kicad_sch, Coprocessor.kicad_sch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]
2022-04-02 Fixing the logical flaws of the dichotomy
    [main.c, timer.c]
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2022-04-06 Modified the BLDC driver circuit by deleting the crystal and adding decoupling capacitors. Replaced the buck chip with JW5017s chip for power supply.
    [Driver.kicad_sch, connector.kicad_sch, controller.kicad_sch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]
2022-04-06 Completed PCB layout wiring of BLDC driver circuit and exported the interactive BOM.
    [project.kicad_pcb]
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2022-04-16 Modifying bugs in unit tests
    [main.c, sensor_decode.c]
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2022-04-17 Optimize the state machine of uart2 DMA receive read_mcu and fix the state that may be wrong
    [main.c, mm32f3x_it.c, sensor_decode.c]
2022-04-17 The main control board circuit modified the CH372C package, changed the serial port of the GPS and ControlMCU back, and moved the components a bit towards the middle so that they could be screwed on.
    [Compass&Storage.kicad_sch, ControlMCU.kicad_sch, Coprocessor.kicad_sch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]
2022-04-21 Updated the main control board circuit to change the GNSS feed line from microstrip line to ribbon line.
    [project.kicad_pcb]
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2022-04-22 Successfully solve the flash writing bug and complete the creation of the file system
    [led.c, main.c, pin.h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]
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2022-04-22 Fix some naming errors
    [main.c]
2022-04-29 Fixed the problem that the status was not switched after exiting the magnetometer calibration page.
    [calibrate_mag_form.c, gps.c, main.c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]
2022-04-29 Reversed the display and fixed a bug that had been hidden in the touch code for years.
    [main.c, xpt2046.c]
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2022-05-04 Added ch372 initialization, but the communication timing is still problematic.
    [config.h, gpio.c, main.c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]
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2022-05-08 1.Added the discernment of whether the position is stable or not 2.When the lqr control comes up with extreme angles, the stuck program stops the car and sends information about the a, b, control_val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
    [main.c]
2022-05-08 Fixed the judgment of GPS stability
    [config.h, main.c]
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2022-05-17 Remove the geomagnetometer from the main control board to enable external connection of the geomagnetometer.
    [Compass&Storage.kicad_sch, ControlMCU.kicad_sch, Coprocessor.kicad_sch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]
2022-05-18 Adding a forecasting process Fix transmission vulnerability
    [main.c, sensor_decode.c]
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2022-05-18 Fixed a bug in communication between ProcessMCU and ControlMCU.
    [sensor_decode.c]
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2022-05-28 Complete the design of the geomagnetometer circuit and update the PCB rules.
    [geomagnetometer.kicad_pcb, geomagnetometer.kicad_sch]
2022-05-29 Modified a portion of the main control board circuit schematic.Added TF card and card reader chip.
    [Flash&USB.kicad_sch, project.kicad_pcb, project.kicad_sch]
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2022-07-09 Fixed part of the control board circuit and added SD card reading chip.
    [Compass&Storage.kicad_sch, ControlMCU.kicad_sch, Coprocessor.kicad_sch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]
2022-07-10 Update the main control board schematic to complete the SD card reader part.
    [Compass&Storage.kicad_sch, ControlMCU.kicad_sch, Coprocessor.kicad_sch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]
2022-07-11 Updated the main control board schematic and switched the geomagnetometer interface sequence.
    [Compass&Storage.kicad_sch, ControlMCU.kicad_sch, Coprocessor.kicad_sch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]
2022-07-11 Complete the master board layout wiring and export the new interactive BOM.
    [project.kicad_pcb]
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2022-07-17 Reduced control frequency of proc_mcu Replaced the trajectory (2w speed will rush into the grass)
    [gps.c, main.c]
2022-07-17 The file system read/write migration was successful. The function was removed because the scan for available space was taking too long.
    [main.c, tfcard.c]
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2022-07-23 Add pop-up stuck code.
    [main.c]
2022-07-23 Solve the geomagnetometer angle problem that has been plaguing us.
    [main.c, sensor_decode.c]
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

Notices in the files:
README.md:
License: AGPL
